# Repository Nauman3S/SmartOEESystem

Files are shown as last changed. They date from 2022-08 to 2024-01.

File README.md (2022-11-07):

<p align="center">
  <a href="" rel="noopener">
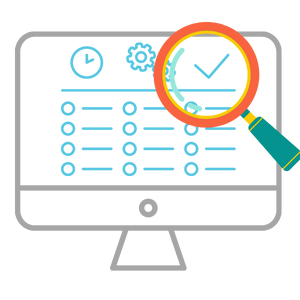
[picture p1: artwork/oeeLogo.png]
Project logo
 </a>
</p>

<h3 align="center">Smart OEE System</h3>

<div align="center">

[]()

</div>

---

<p align="center"> Smart OEE System
    <br> 
</p>

## 📝 Table of Contents

- [About](#about)
- [Getting Started](#getting_started)
- [RPiClient Installation](#Installation)
- [Circuit](#circuit)
- [Usage](#usage)
- [WebApp](#webapp)
- [Built Using](#built_using)
- [Authors](#authors)

## 🧐 About 

This repo contains

- Firmware
- Circuit Diagram
- Detailed instructions

for Smart OEE System.

## Getting Started 

These instructions will get you a copy of the project up and running on your system.

### Prerequisites

Things you need to install the FW.

```
- Arduino IDE
```

### Installing 

A step by step series that tell you how to get the Firmware and Backend running

#### ESP32 Configuration

You should have Arduino IDE Installed

  1.  Add ESP32 Board to your Arduino IDE
    1. In your Arduino IDE, go to File> Preferences
        Installing ESP32 Add-on in Arduino IDE Windows, Mac OS X, Linux open preferences
    2. Enter ```https://dl.espressif.com/dl/package_esp32_index.json``` 
        into the “Additional Board Manager URLs” field then, click the “OK” button:
        Note: if you already have the ESP32 boards URL, you can separate the URLs with a comma(each board will go to neaw line) as follows:
        ```https://dl.espressif.com/dl/package_esp32_index.json,\n http://arduino.esp8266.com/stable/package_esp8266com_index.json```

  2. Open the Boards Manager. Go to Tools > Board > Boards Manager…
  3. Search for ESP32 and press install button for the ESP32 by Espressif Systems“:
  4. That’s it. It should be installed after a few seconds.
  5.   In your Arduino sketchbook directory, create tools directory if it doesn't exist yet.
  6.  Unpack the tool into tools directory(present in libs/ESP32FS-1.0.zip) (the path will look like <home_dir>/Arduino/tools/ESP32FS/tool/esp32fs.jar).
  7.  Close and re-open the Arduino IDE.

  8.  Now copy the contents of the libs folder to the libraries directory of your Arduino
      1. If you are using windows, the libraries directory will be Documents/Arduino/libraries

##### ESP32 Node FW Uploading
  1.  Select ESP32 Dev Module from Tools->Board->ESP32
  2.  Select the correct port from Tools->Port
  3.  Then open Firmware.ino file,
  4.  Select Tools > ESP32 Sketch Data Upload menu item. This should start uploading the files into ESP32 flash file system.
  5.  Now Upload the Code to your ESP32 Dev Module.
  6.  Your ESP32 is now ready to be used.

## Circuit 

### ESP32 Dev Module Pinout

Follow the pinout diagram given below to connect different components to your TTGO LORA32 board.

![LoraPinout](Circuit/ESP32-Pinout.jpg)

### Other Components

```http
Other components pin connection details
```

#### Temperature Sensor DHT22

```DHT22 Connections```

| DHT22 Pins | ESP32 Dev Module Pins| 
| :--- | :--- | 
| `DATA OUT` | `23` |
| `VCC` | `5V` |
| `GND` | `GND` | 

#### Photoelectric Sensor

```Photoelectric Sensor Connections```

`From 2x 10K Resistors' center to Pin 18 of ESP32`

#### Status LED

```LED Connections```

| LED Pins | ESP32 Dev Module | 
| :--- | :--- | 
| `Anode` | `D2 via 220Ω resistor` |
| `Cathode` | `GND` |
*D2 is also connected to the internal LED of ESP32 Dev Module*

#### SCT-013 

```SCT-013 Connections```

-   Voltage Divider with 2x 100KΩ resistors.
-   10uF capacitor connected between Voltage Divider Circuit Output and GND
-   3.5mm Audio Jack connected between Voltage Divider Circuit Output and ESP32 Pin 34.

The overall SCT-013 connection assembly will look something like shown in the diagram below.

![SCTConnection](Circuit/sctWiring.jpg)

The photoelectric sensor has three wires as shown below

![PESConnection](Circuit/pesSch.jpg)

### Complete Circuit Diagram

Here's the complete circuit diagram of the system.

![CircuitDiagram](Circuit/Circuit_bb.png)

## Usage 

1.  Power on your ESP32, it will present you with an AP named ```OEE``` (while ```OEE``` can be changed in the portal)
2.  Default captive portal password `12345678AP` which can be changed in captive portal.
3.  Connect to the ESP32 access point and open the web-browser and navigate to the link ```http://esp32.local/_ac```. This link will work on most of the operating systems but if your operating system is not allowing to open it, you may want to check the captive portal IP Address from the serial monitor and can use that IP address inplace of the above mentioned URL.
4.  The default access IP Address is ```http://192.168.4.1/_ac```
5.  You will be presented with a main dashboard as shown below(based on your device)
   ![SCR1](artwork/scr1.png)

5.  Once connected to a WiFi network, you can again access the captive portal using same URL or the IP Address from the Serial monitor.
6.  The data is published to the MQTT Topic ```OEE/{hostname}``` while the hostname is the one which you can define in Settings page of the captive portal.

### Changing Timezone

1.  Open Settings tab
2.  Enter timezone string from https://en.wikipedia.org/wiki/List_of_tz_database_time_zones 'TZ database name' column.
3.  Click Save&Start

### API Endpoints and HTML URLS
```API Endpoints```

| Endpoint | Description | 
| :--- | :--- | 
| `/api-now` | `API: live sensor readings in JSON format` |
| `/api` | `API: historical sensors data in JSON format` |
| `/LiveSensors` | `HTML PAGE: Live Sensor Data` |
| `/data` | `HTML PAGE: Historical Sensor Data` | 
| `/mqtt_settings` | `HTML PAGE: Settings. Default username: AP Name, Default Password: admin` | 
| `/_ac` | `HTML PAGE: Main Captive portal page` | 
| `/` | `HTML PAGE: Historical Sensor Data` | 

1.  **Connect to WiFi** tab allows searching of nearby WiFi APs and adding them to the ESP32.
   ![SCR3](artwork/scr3.png)
7.  **Saved WiFi Networks** tab allows connecting to the saved access points.
   ![SCR4](artwork/scr4.png)
8.  **Reset...** tab allows reseting of the device to factory settings.
    ![SCR5](artwork/scr5.png)
9.  **Settings** tab contains settings related to MQTT and sensors.
    ![SCR6](artwork/scr6.png)
10. **api-now** tab gives the live-sensor data in JSON format.
    ![SCR7](artwork/scr7.png)
11. **api** tab gives the historical sensor data acquired after every 5 mintues.
    ![SCR9](artwork/scr9.png)
13. **LiveSensors** tab shows live values of the sensors.
    ![SCR8](artwork/scr8.png)
12. **HOME** tab shows historical sensor data in a HTML table form acquired after every 5 minutes.
    ![SCR10](artwork/scr10.png)

## Web App 

[Dashboard Link: https://smartoeesystem.production.rehanshakir.com/](https://smartoeesystem.production.rehanshakir.com/)

You can access the webapp with following test acccount credentials

**Test Client**

*   Email Address: `howto0158@gmail.com`
*   Password: `1234`

**Admin**

*   Email Address: `admin@smartoee.com`
*   Password: `12345678`

### Dashboard Screenshots

 ![SCR11](artwork/db1.png) - Sign-in
 ![SCR12](artwork/db2.png) - Sign-up

 **Admin Dashboard**

 ![SCR13](artwork/db3.png) - Main Dashboard
 ![SCR14](artwork/db4.png) - Devices/Sensors Page
 ![SCR15](artwork/db5.png) - Adding a new Device/Sensor
 ![SCR16](artwork/db6.png) - Devices Management Page
 ![SCR17](artwork/db7.png) - User Profile

 **Client Dashboard**
 ![SCR18](artwork/cdb1.png) - Main Client Dashboard
 ![SCR19](artwork/cbd2.png) - Updating energy cost
 ![SCR20](artwork/cdb3.png) - Devices Management
 ![SCR21](artwork/cdb4.png) - Adding a new device
 ![SCR22](artwork/cdb5.png) - User Profile

### MQTT Details

From Device the data should be published to the topic `smartoee/data/#` in the format below:
* Replace `#` with the device MAC Address.

```json
{
  "macAddress": "FE064CSF",
  "oee":"20",
  "temperature":"30",
  "humidity":"45",
  "watts":"19"
}
```

Any change detected in the values will generate an alarm(as set in the dashboard) and will publish the value on the topic `{MAC Address}/smartoee` of the device.

## List of Components 

Following components are used to make this project

1.  [ESP32 Dev Kit Module](https://www.amazon.com/HiLetgo-ESP-WROOM-32-Development-Microcontroller-Integrated/dp/B0718T232Z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)

2.  [Current Sensor (SCT-013)](https://www.amazon.com/dp/B083S6YG36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)

or

2.  [Current Sensor 200A](https://www.amazon.com/Current-Sensor-Transformer-Energy-Meter/dp/B0B91R55TS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)

3.  [DHT22 Temperature and Humidity Sensor](https://www.amazon.com/Gowoops-Temperature-Humidity-Measurement-Raspberry/dp/B073F472JL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)

4.  [Vibration Sensor (IMU) (MPU6050)](https://www.amazon.com/HiLetgo-MPU-6050-Accelerometer-Gyroscope-Converter/dp/B00LP25V1A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)

5. [Photoelectric Sensor](https://www.amazon.com/IKSACE-Photoelectric-Switchable-Retroreflective-photoelectric/dp/B08KRQ7M1P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)

6.  [Generic 3.5mm Green/Red/Blue LEDs](https://www.amazon.com/MCIGICM-Circuit-Assorted-Science-Experiment/dp/B07PG84V17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)

7.  [Generic 3.5mm Audio Jack with Screw Terminals](https://www.amazon.com/Cerrxian-Terminal-Headphone-Converter-Adapter/dp/B06WRRGYMM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)

8.  [Generic 10uF 25v Capacitor](https://www.amazon.com/Tnisesm-Electrolytic-Capacitor-Aluminum-10UF-25V-4X7/dp/B089YCK59V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)

9.  [Generic 220Ω Resistors](https://www.amazon.com/BOJACK-Single-Resistor-Resistors-200pcs/dp/B07PFFF1VK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)

10. [Generic 10KΩ Resistors](https://www.amazon.com/EDGELEC-Resistor-Tolerance-Multiple-Resistance/dp/B07QJB31M7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)

11. [Generic 100KΩ Resistors](https://www.amazon.com/Resistor-Tolerance-Resistors-Limiting-Certificated/dp/B08QRSQB18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)

12.  [Generic 5V USB Micro B cable and adapter](https://www.amazon.com/Travel-Charger-Adapter-Samsung-Galaxy/dp/B0117O020U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)

13. [Micro USB Cable](https://www.amazon.com/Android-Charger-sweguard-Charging-Phone-Grey/dp/B09MT18H3J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)

14. [Breadboard, Jumper Wires and Power Supply Module](https://www.amazon.com/HUAREW-Breadboard-Wires%EF%BC%8CBattery-Clip%EF%BC%8C830-tie-Points/dp/B09TX9CMG1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)

15. [Jumper Wires](https://www.amazon.com/EDGELEC-Breadboard-Optional-Assorted-Multicolored/dp/B07GD2BWPY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)

16. [12V 3A Adapter](https://www.amazon.com/GOOKYO-Charger-Switching-Replacement-Adapter/dp/B095S61GFH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)

## ⛏️ Built Using 

- [Python](https://www.python.org/) - For Cloud Gateway Pogramming
- [Arduino](https://www.arduino.cc/) - Embedded Framework and IDE - For Sensor Node Design

## 📹 Demo Videos 

-   [Device Demo Video](https://youtu.be/jB85V6VlB9w) - OEE Device Demo Video

## ✍️ Authors 

- [@Nauman3S](https://github.com/Nauman3S) - Development and Deployment

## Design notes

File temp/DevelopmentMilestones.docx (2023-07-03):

Below, provided is the rough time estimates for simple implementation of each feature, assuming that the current backend infrastructure (NodeJS), frontend (ReactJS), and database (MongoDB) are all in good shape and dockerized using CapRover. Please note that these estimates are tentative and subject to change based on potential unforeseen complexities or challenges:

1. Display production line name: 2 days. This requires creating an input field, updating the database schema, and allowing for real-time updates.
2. Product Name: 2 days. Similar to feature 1, this also requires real-time updates.
3. Display running (green) Line Stopped (red): 3-4 days. This involves reading sensor data in real-time and updating the display based on predefined conditions.
4. Shift Start Time: 2 days. The system needs to recognize when a shift starts, based on sensor data or user input.
5. Shift Duration timer: 2-3 days. This involves real-time tracking of shift duration.
6. Shift Downtime: 3-4 days. Implementing this feature involves keeping track of sensor inactivity and calculating downtime as a percentage of total shift time.
7. Units Per Minute: 3-4 days. The system must track production units in real-time and calculate a rate per minute.
8. Target Today: 2 days. This feature requires an input field for target setting and updating the database schema.
9. Progress Chart: 4-5 days. This feature requires generating and updating a real-time progress chart based on current progress against target.
10. OEE Chart: 4-5 days. The system must calculate OEE (Overall Equipment Efficiency) parameters and display them in a dynamic chart.
11. Line Performance Each Day: 4-5 days. This feature involves storing daily data and generating bar charts.
12. Client can print report/PDF: 4-5 days. The system must compile data into a report and generate a PDF that the user can print.

Total Development Time Required: 36 - 43 days

These timeframes are rough estimates and assume an uninterrupted workflow. Testing, bug fixing, and additional adjustments could potentially extend these estimates further. Each feature will require careful design, implementation, and testing to ensure its seamless integration with the existing system. If the list of requirements increases or the specifics of these features become more complex, the timeline would also need to be adjusted accordingly.

Please keep in mind that any significant alterations to the backend might require additional time, especially if they impact the underlying database schema or the data handling processes.

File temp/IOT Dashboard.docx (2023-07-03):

IOT Dashboard

Dashboard will have cpanel login specific to each client. Each client will have multiple production lines displayed on the home screen. As per chat, the admin can add sensors, data etc. It shows real time & date.

The formula’s and displays required:

1. Display production line name: Eg: Line 1 (edited by user)
2. Product Name: (edited by user)
3. Display running (green) Line Stopped (red)
4. Shift Start Time:
5. Shift Duration: timer
6. Shift Downtime: (minutes) also display as % of total shift duration
7. Units Per Minute (calculated per minute)
8. Target Today: (edited by user)
9. Progress Chart: Showing on target, not on target, progress bar. Showing total units produced currently.
10. OEE chart (traffic light %)
11. Line Performance Each Day: Showing bar chart for each day Monday – Sunday of the past week.
1. Box to display name of line: eg: Pouch Line / Line 1 (edited by user)
2. Box to display name of product: eg: Chocolate Biscuit (edited by user)
3. Running in green or Line Stopped in red. (Green if photo electric sensor at beginning of line is activated consistently for 15 seconds. Red if photo electric sensor is not activated during 60 second period.
4. As soon as sensor is activated at beginning of day.
5. Timer set once shift starts
6. Number of minutes there is downtime / no activation of photo sensors beginning & end of line. (% downtime formula is number of minutes / total shift time)
7. Units per minute calculation box (calculated each minute) shows graph of units per minute per minute / per hour
8. Target Today (Set / edited by user)
9. Progress Chart (ON TARGET / NOT ON TARGET) Progress Bar showing 0 – 100% (based on user setting target). Showing total units produced currently.
10. OEE Chart (circle – performance, availability, quality)
11. Displays total values of each line each day by total units.
12. Client can print report / PDF for each line or total lines for each day.

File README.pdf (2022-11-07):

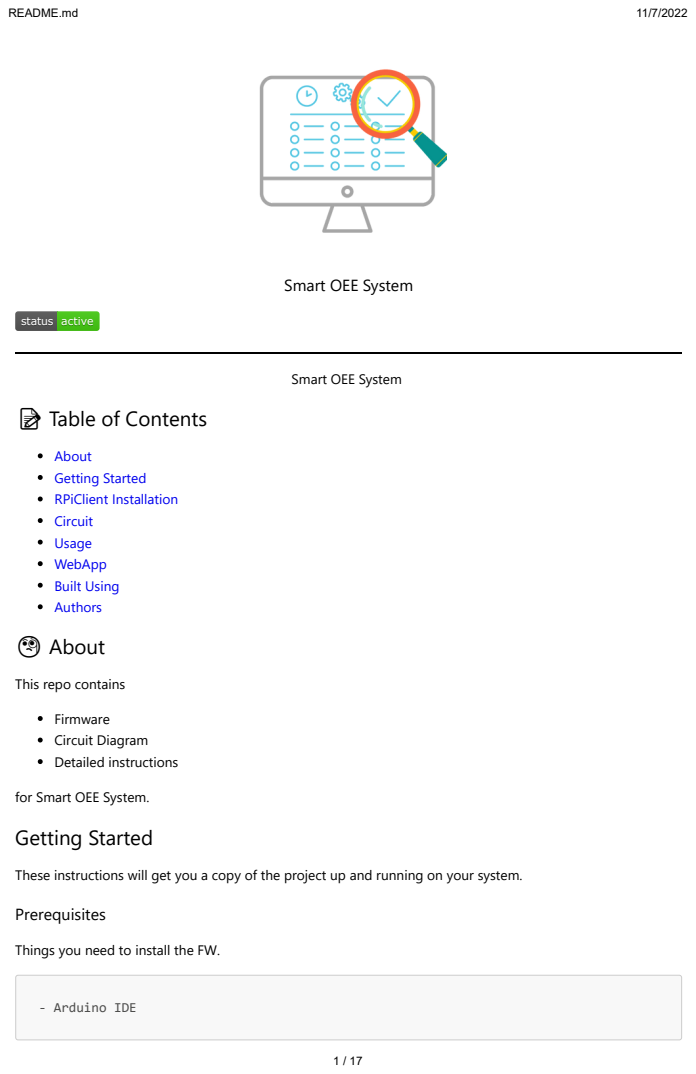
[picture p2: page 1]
README.md; ssttaattuuss; aaccttiivvee; About Getting Started RPiClient Installation Circuit Usage WebApp Built Using Authors 🧐 About; Firmware Circuit Diagram Detailed instructions; - Arduino IDE

Smart OEE System

📝 Table of Contents

This repo contains

for Smart OEE System.
Getting Started

These instructions will get you a copy of the project up and running on your system.
Prerequisites

Things you need to install the FW.

Installing

A step by step series that tell you how to get the Firmware and Backend running

ESP32 Configuration

You should have Arduino IDE Installed

1. Add ESP32 Board to your Arduino IDE 1. In your Arduino IDE, go to File> Preferences Installing ESP32 Add-on in Arduino IDE Windows, Mac OS X, Linux open preferences 2. Enter https://dl.espressif.com/dl/package_esp32_index.json into the “Additional Board Manager URLs” field then, click the “OK” button: Note: if you already have the ESP32 boards URL, you can separate the URLs with a comma(each board will go to neaw line) as follows: https://dl.espressif.com/dl/package_esp32_index.json,\nhttp://arduino.esp8266.com/stable/package_esp8266com_index.json
2. Open the Boards Manager. Go to Tools > Board > Boards Manager…
3. Search for ESP32 and press install button for the ESP32 by Espressif Systems“:
4. That’s it. It should be installed after a few seconds.
5. In your Arduino sketchbook directory, create tools directory if it doesn't exist yet.
6. Unpack the tool into tools directory(present in libs/ESP32FS-1.0.zip) (the path will look like <home_dir>/Arduino/tools/ESP32FS/tool/esp32fs.jar).
7. Close and re-open the Arduino IDE.
8. Now copy the contents of the libs folder to the libraries directory of your Arduino
1. If you are using windows, the libraries directory will be Documents/Arduino/libraries

ESP32 Node FW Uploading

1. Select ESP32 Dev Module from Tools->Board->ESP32
2. Select the correct port from Tools->Port
3. Then open Firmware.ino file,
4. Select Tools > ESP32 Sketch Data Upload menu item. This should start uploading the files into ESP32 flash file system.
5. Now Upload the Code to your ESP32 Dev Module.
6. Your ESP32 is now ready to be used.

## Circuit

ESP32 Dev Module Pinout

Follow the pinout diagram given below to connect different components to your TTGO LORA32 board.

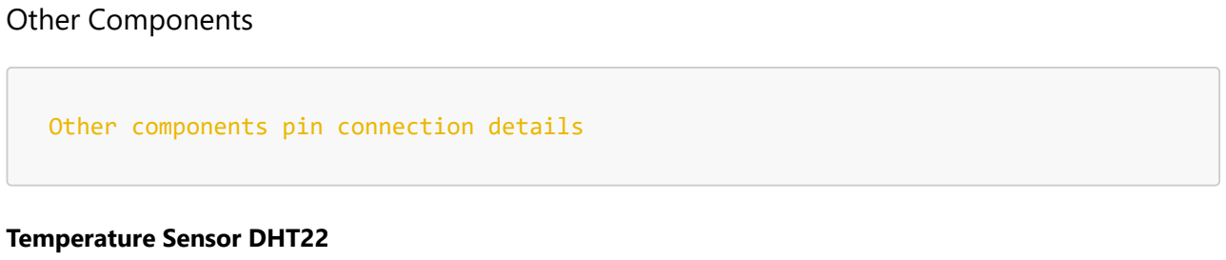
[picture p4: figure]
Other Components; Other components pin connection details; Temperature Sensor DHT22

DHT22 Connections

DHT22 Pins ESP32 Dev Module Pins

DATA OUT | 23
VCC | 5V
GND | GND

Photoelectric Sensor

Photoelectric Sensor Connections

From 2x 10K Resistors' center to Pin 18 of ESP32

Status LED

LED Connections

LED Pins ESP32 Dev Module

LED Pins ESP32 Dev Module

Anode | D2 via 220Ω resistor
Cathode | GND

D2 is also connected to the internal LED of ESP32 Dev Module

SCT-013

SCT-013 Connections

Voltage Divider with 2x 100KΩ resistors.
10uF capacitor connected between Voltage Divider Circuit Output and GND
3.5mm Audio Jack connected between Voltage Divider Circuit Output and ESP32 Pin 34.

The overall SCT-013 connection assembly will look something like shown in the diagram below.

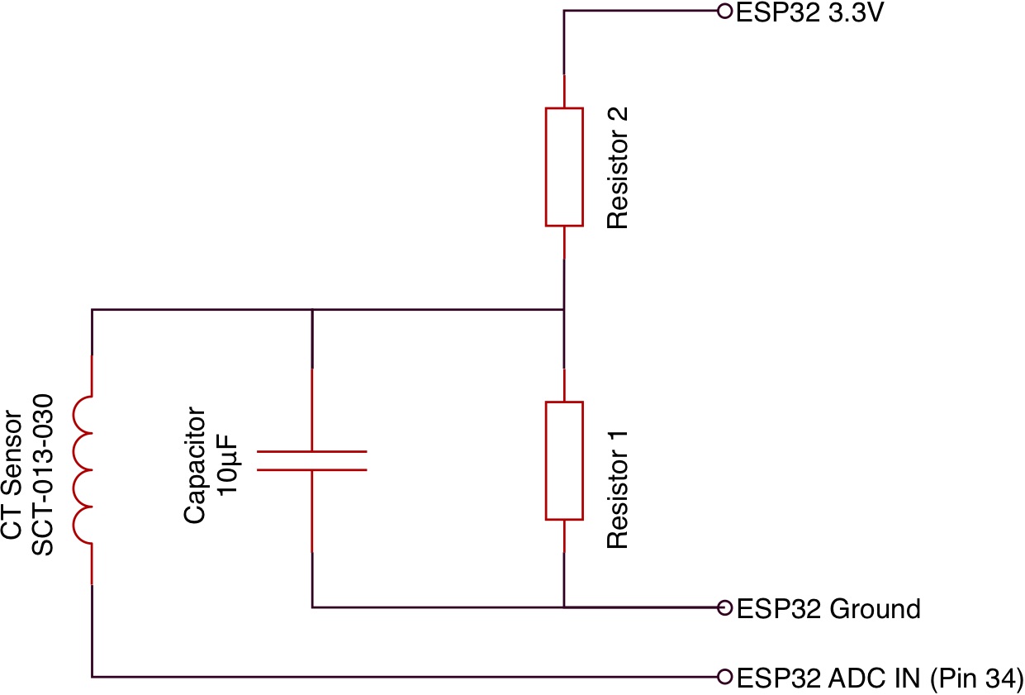
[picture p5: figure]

The photoelectric sensor has three wires as shown below

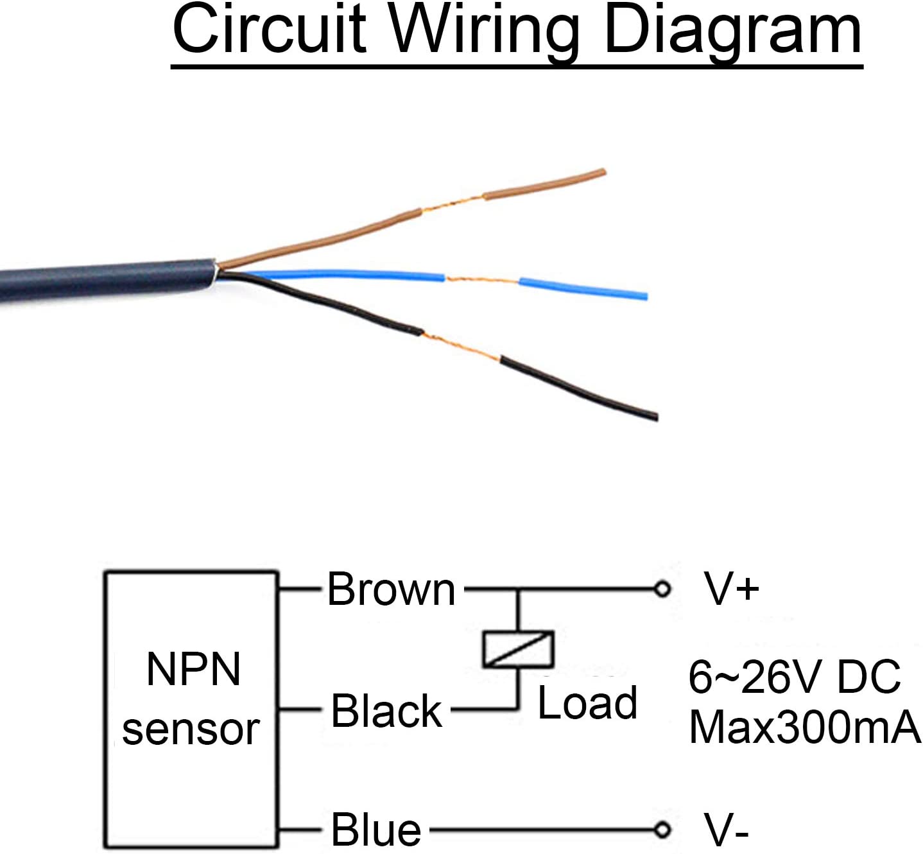
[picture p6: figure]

Complete Circuit Diagram

Here's the complete circuit diagram of the system.

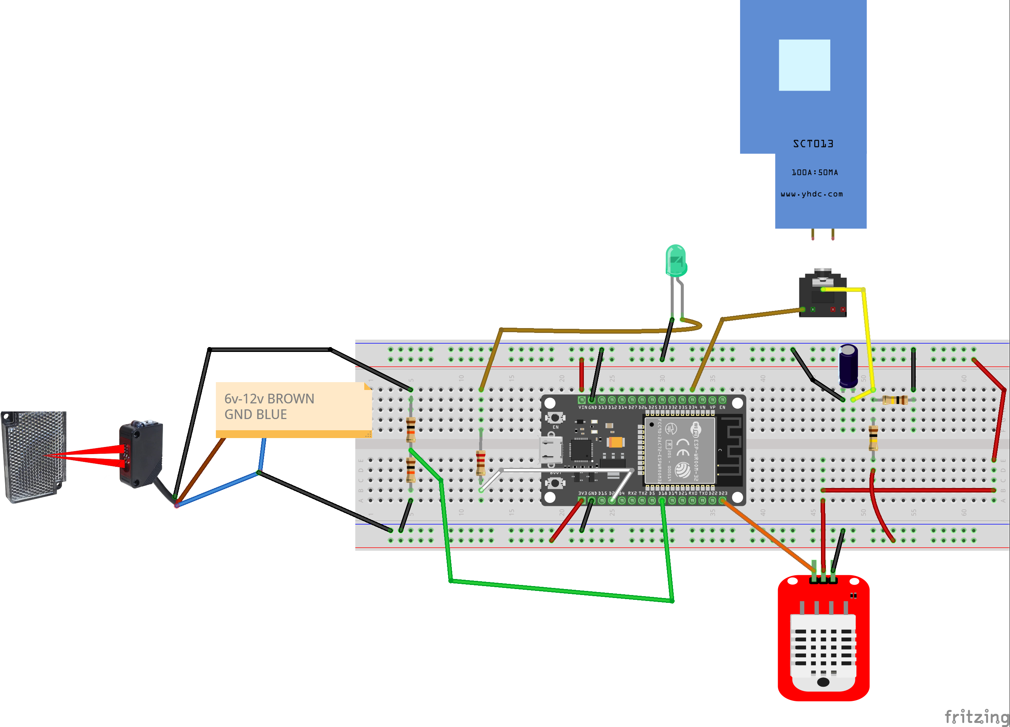
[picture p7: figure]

## Usage

1. Power on your ESP32, it will present you with an AP named OEE (while OEE can be changed in the portal)
2. Default captive portal password 12345678AP which can be changed in captive portal.
3. Connect to the ESP32 access point and open the web-browser and navigate to the link http://esp32.local/_ac. This link will work on most of the operating systems but if your operating system is not allowing to open it, you may want to check the captive portal IP Address from the serial monitor and can use that IP address inplace of the above mentioned URL.
4. The default access IP Address is http://192.168.4.1/_ac

5. You will be presented with a main dashboard as shown below(based on your device)

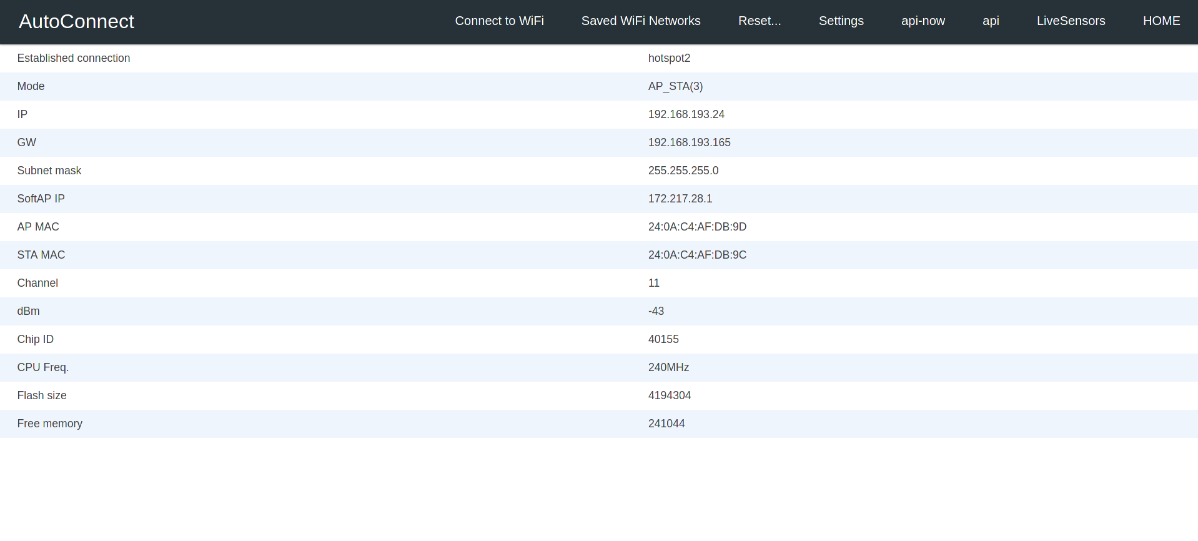
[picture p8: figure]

6. Once connected to a WiFi network, you can again access the captive portal using same URL or the IP Address from the Serial monitor.
7. The data is published to the MQTT Topic OEE/{hostname} while the hostname is the one which you can define in Settings page of the captive portal.
Changing Timezone
1. Open Settings tab
2. Enter timezone string from https://en.wikipedia.org/wiki/List_of_tz_database_time_zones 'TZ database name' column.
3. Click Save&Start
API Endpoints and HTML URLS

API Endpoints

Endpoint | Description
/api-now | API: live sensor readings in JSON format
/api | API: historical sensors data in JSON format
/LiveSensors | HTML PAGE: Live Sensor Data
/data | HTML PAGE: Historical Sensor Data
/mqtt_settings | HTML PAGE: Settings. Default username: AP Name, Default Password: admin
/_ac | HTML PAGE: Main Captive portal page
/ | HTML PAGE: Historical Sensor Data

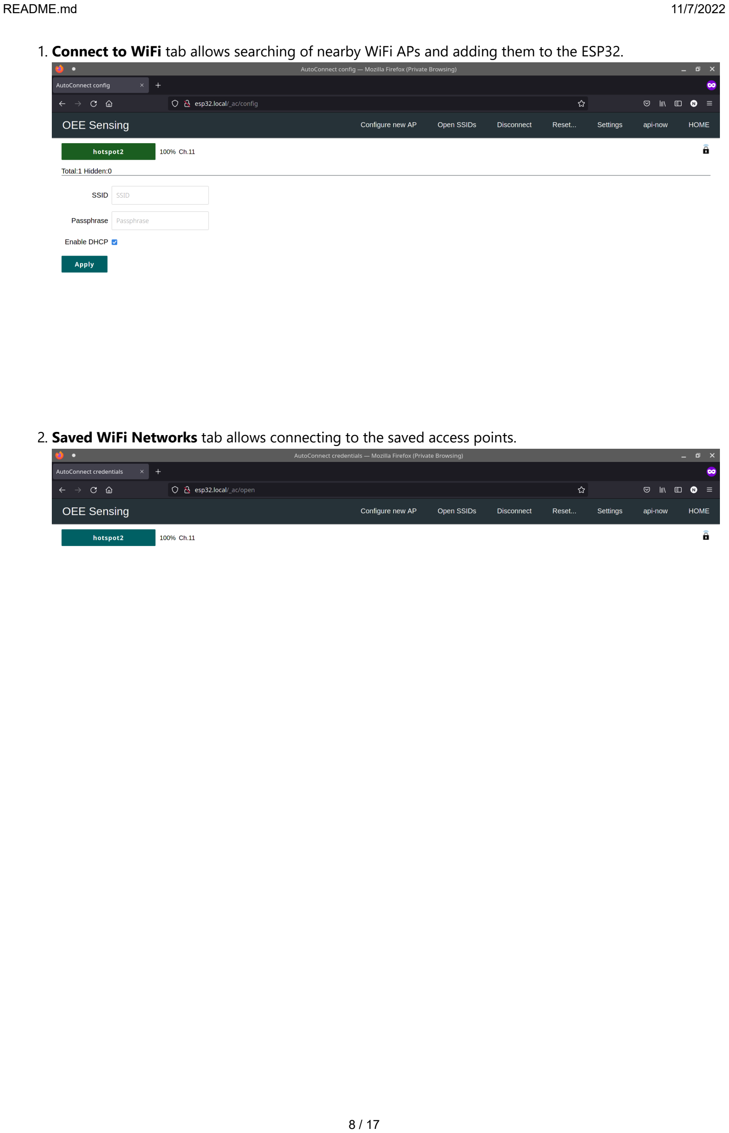
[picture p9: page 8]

1. Connect to WiFi tab allows searching of nearby WiFi APs and adding them to the ESP32.
2. Saved WiFi Networks tab allows connecting to the saved access points.

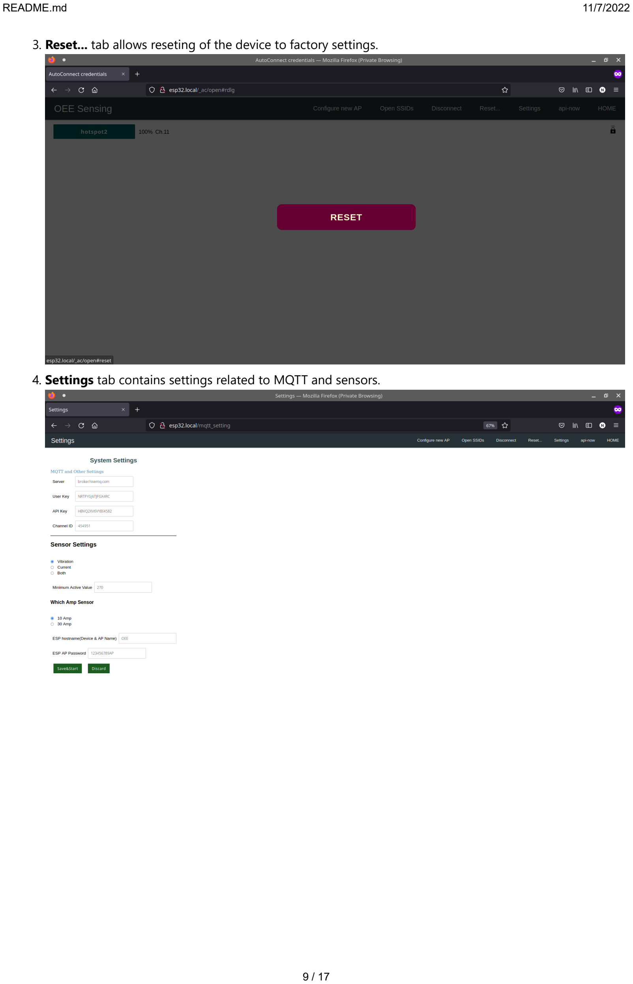
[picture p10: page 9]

3. Reset... tab allows reseting of the device to factory settings.
4. Settings tab contains settings related to MQTT and sensors.

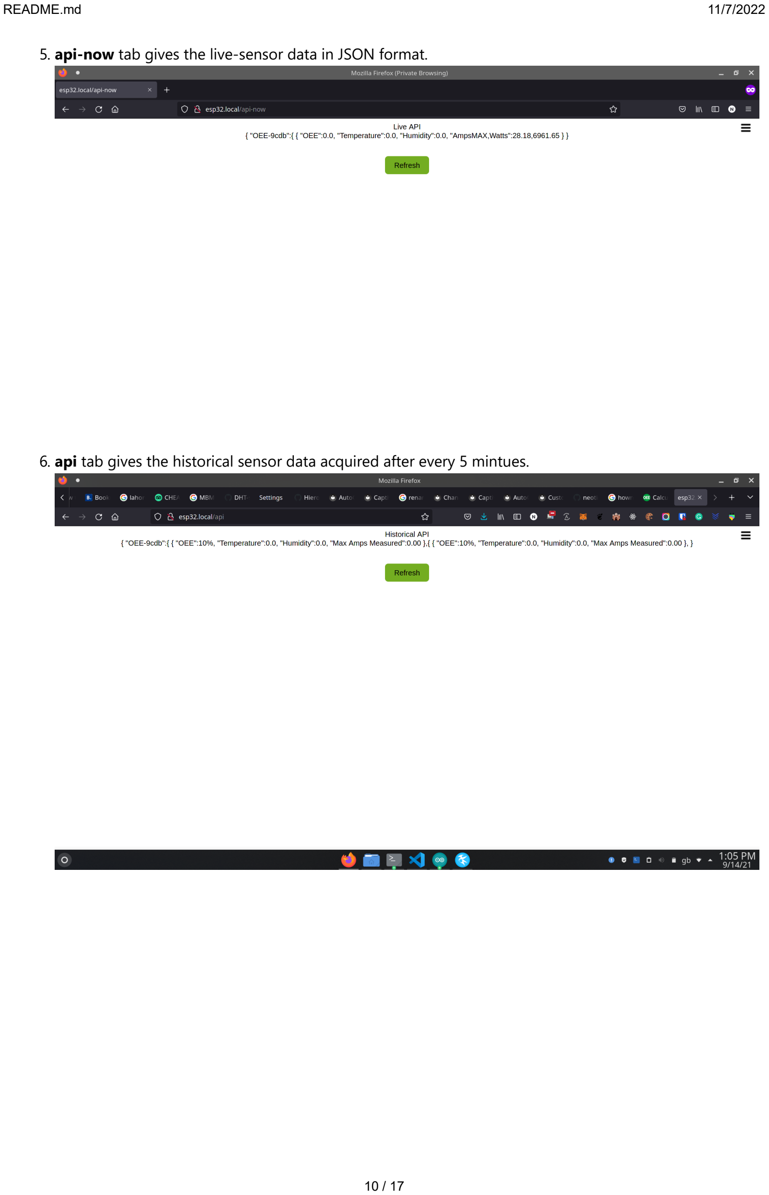
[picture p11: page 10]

5. api-now tab gives the live-sensor data in JSON format.
6. api tab gives the historical sensor data acquired after every 5 mintues.

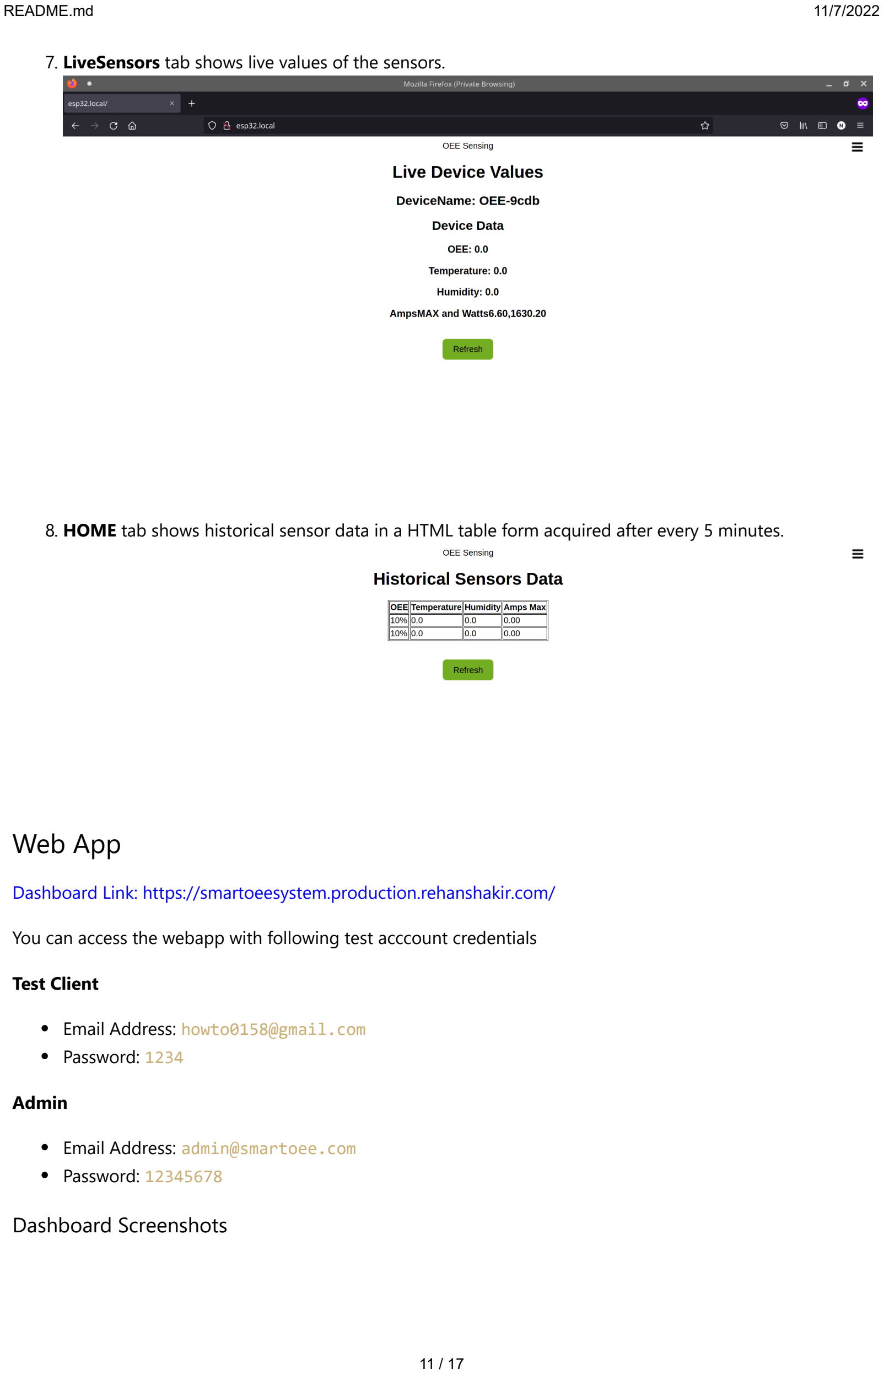
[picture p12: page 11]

7. LiveSensors tab shows live values of the sensors.
8. HOME tab shows historical sensor data in a HTML table form acquired after every 5 minutes.

## Web App

Dashboard Link: https://smartoeesystem.production.rehanshakir.com/

You can access the webapp with following test acccount credentials

Test Client

Email Address: howto0158@gmail.com
Password: 1234

Admin

Email Address: admin@smartoee.com Password: 12345678
Dashboard Screenshots

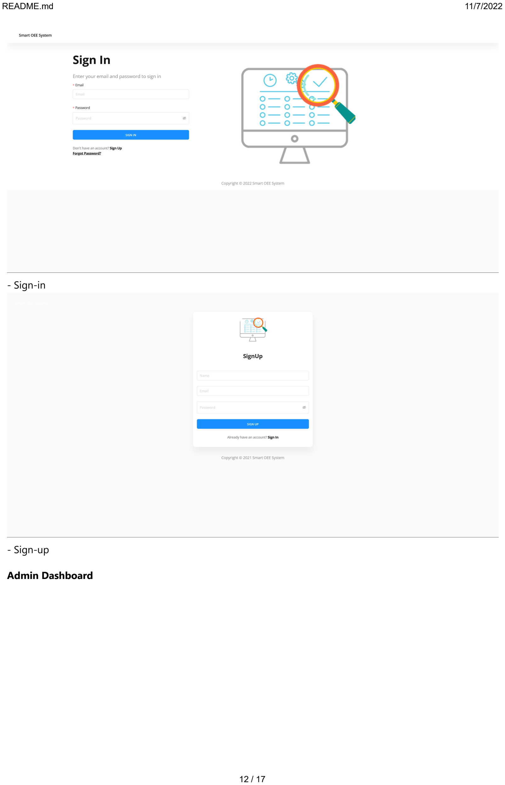
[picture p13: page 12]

- Sign-in
- Sign-up

Admin Dashboard

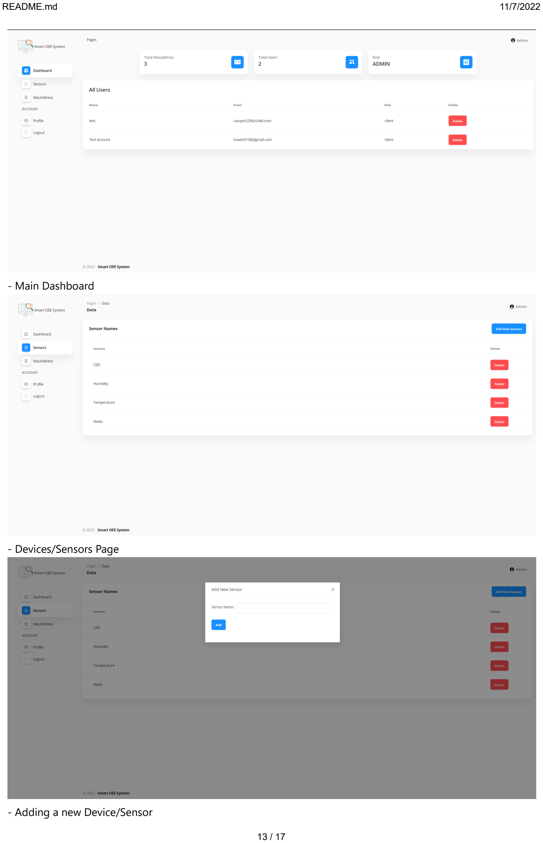
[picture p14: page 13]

- Main Dashboard
- Devices/Sensors Page
- Adding a new Device/Sensor

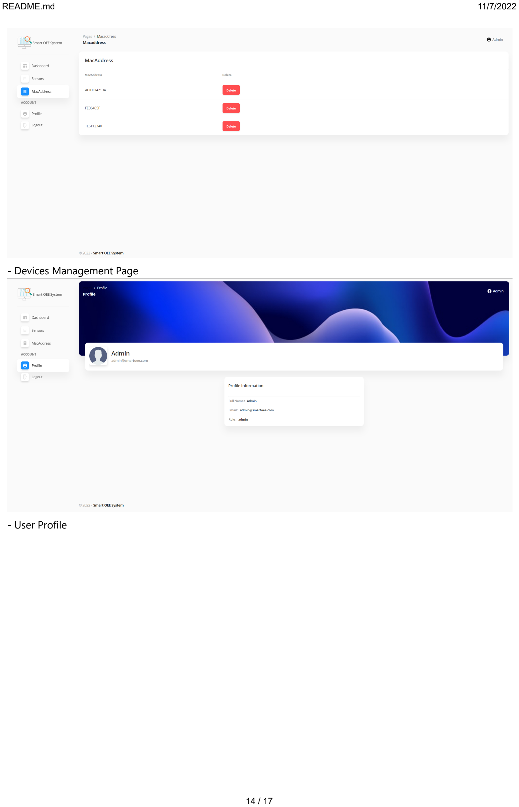
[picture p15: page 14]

- Devices Management Page
- User Profile

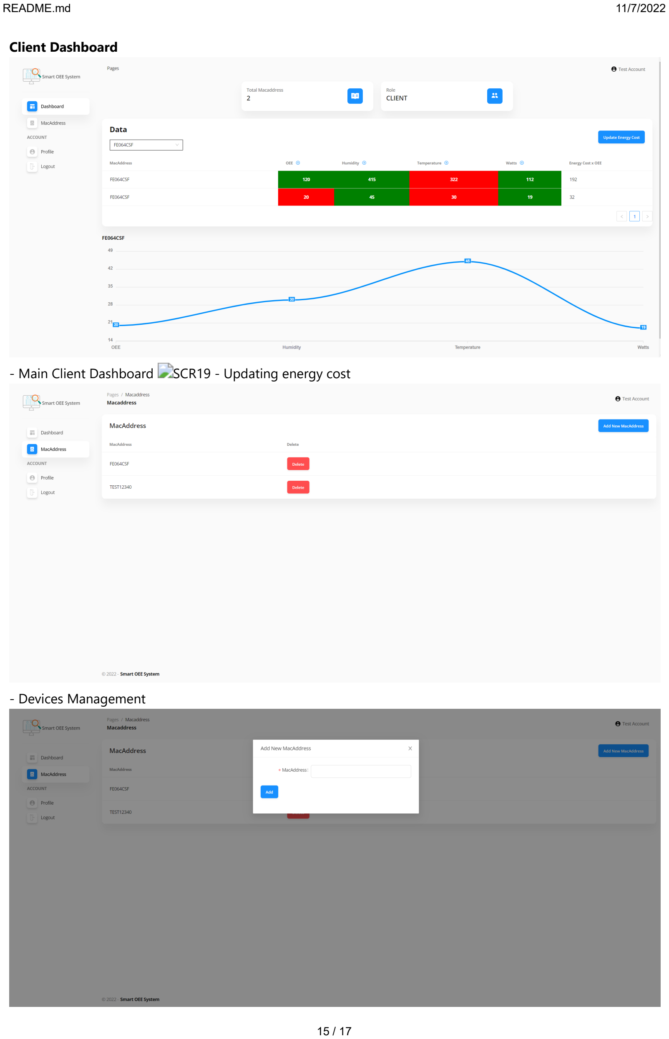
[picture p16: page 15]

Client Dashboard

- Main Client Dashboard SCR19 - Updating energy cost
- Devices Management

- Adding a new device

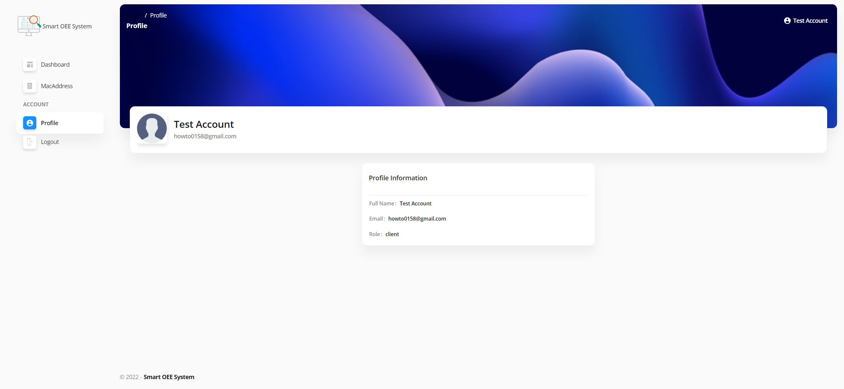
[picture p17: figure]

- User Profile
MQTT Details

From Device the data should be published to the topic smartoee/data/# in the format below

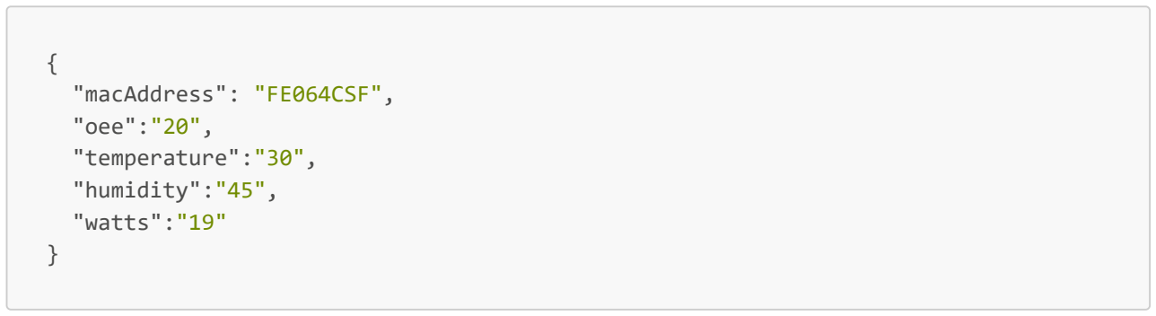
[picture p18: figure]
"macAddress": "FE064CSF", "oee":"20", "temperature":"30", "humidity":"45", "watts":"19"

Any change detected in the values will generate an alarm(as set in the dashboard) and will publish the value on the topic {MAC Address}/smartoee of the device.

## List of Components

Following components are used to make this project

1. ESP32 Dev Kit Module (https://www.amazon.com/HiLetgo-ESP-WROOM-32-Development-Microcontroller-Integrated/dp/B0718T232Z)
2. Current Sensor (SCT-013) (https://www.amazon.com/dp/B083S6YG36)

or

2. Current Sensor 200A (https://www.amazon.com/Current-Sensor-Transformer-Energy-Meter/dp/B0B91R55TS)
3. DHT22 Temperature and Humidity Sensor (https://www.amazon.com/Gowoops-Temperature-Humidity-Measurement-Raspberry/dp/B073F472JL)
4. Vibration Sensor (IMU) (MPU6050) (https://www.amazon.com/HiLetgo-MPU-6050-Accelerometer-Gyroscope-Converter/dp/B00LP25V1A)
5. Photoelectric Sensor (https://www.amazon.com/IKSACE-Photoelectric-Switchable-Retroreflective-photoelectric/dp/B08KRQ7M1P)

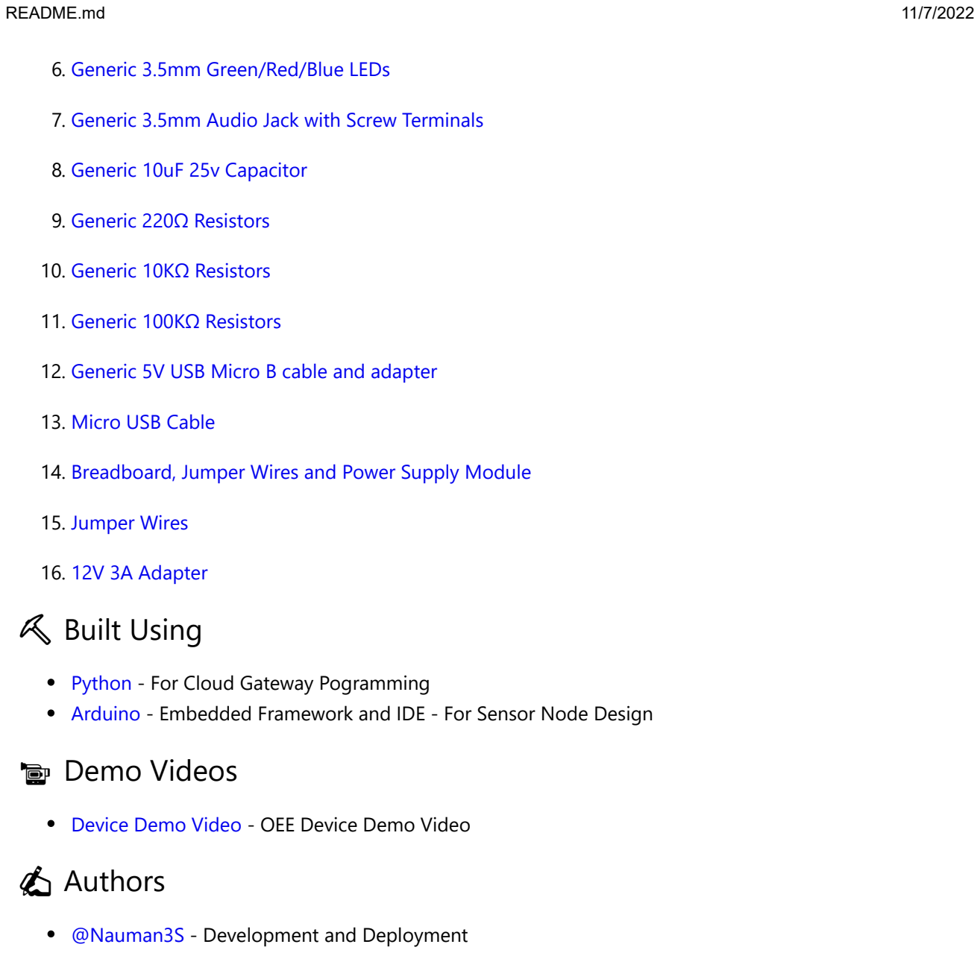
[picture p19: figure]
6. Generic 3.5mm Green/Red/Blue LEDs; 8. Generic 10uF 25v Capacitor; 9. Generic 220Ω Resistors; 10. Generic 10KΩ Resistors; 11. Generic 100KΩ Resistors; 13. Micro USB Cable; 15. Jumper Wires; 16. 12V 3A Adapter ⛏ Built Using; Python - For Cloud Gateway Pogramming; 📹 Demo Videos; ✍ Authors; @Nauman3S - Development and Deployment

7. Generic 3.5mm Audio Jack with Screw Terminals (https://www.amazon.com/Cerrxian-Terminal-Headphone-Converter-Adapter/dp/B06WRRGYMM)
12. Generic 5V USB Micro B cable and adapter (https://www.amazon.com/Travel-Charger-Adapter-Samsung-Galaxy/dp/B0117O020U)
14. Breadboard, Jumper Wires and Power Supply Module (https://www.amazon.com/HUAREW-Breadboard-Wires%EF%BC%8CBattery-Clip%EF%BC%8C830-tie-Points/dp/B09TX9CMG1)

Arduino (https://www.arduino.cc/) - Embedded Framework and IDE - For Sensor Node Design

Device Demo Video (https://youtu.be/jB85V6VlB9w) - OEE Device Demo Video

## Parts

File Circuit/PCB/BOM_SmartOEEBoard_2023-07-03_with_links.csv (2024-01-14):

ID | Name | Designator | Footprint | Quantity | Manufacturer Part | Manufacturer | Supplier | Supplier Part | Price | Resistance (Ohms) | link
1 | 10uF | C1,C4,C10 | C0603 | 3 | 0603X106K100CT | Walsin(华新科) | LCSC | C2840513 | 0.011 |  | https://www.lcsc.com/product-detail/Multilayer-Ceramic-Capacitors-MLCC-SMD-SMT_Walsin-Tech-Corp-0603X106K100CT_C2840513.html
2 | 10uF | C2,C6,C8 | C0603 | 3 | C0603X5R106M160NT | SANYEAR(叁叶源) | LCSC | C466781 | 0.027 |  | https://www.lcsc.com/product-detail/Multilayer-Ceramic-Capacitors-MLCC-SMD-SMT_SANYEAR-C0603X5R106M160NT_C466781.html
3 | 1uF | C3,C5,C7 | C0603 | 3 | CC0603KRX7R6BB105 | YAGEO(国巨) | LCSC | C113807 | 0.008 |  | https://www.lcsc.com/product-detail/Multilayer-Ceramic-Capacitors-MLCC-SMD-SMT_YAGEO-CC0603KRX7R6BB105_C113807.html
4 | THT Pad | J1,J2,J3,J4,J5,J6,J7,J8,J9,J10,J11,J12,J14,J15,J16,J19,J20,J21,J22,J32,J34,J35,J36,J37,J38 | THT PAD | 25
5 | LTL-4221N | LED2 | LED-TH_BD3.0-P2.54-RD-RED | 1 | LTL-4221N | LITEON(光宝) | LCSC | C125081 | 0.046 |  | https://www.lcsc.com/product-detail/Light-Emitting-Diodes-LED_Lite-On-LTL-4221N_C125081.html
6 | XL-304UBC | LED3 | LED-TH_BD3.8-P2.54-FD_BLUE | 1 | XL-304UBC | XINGLIGHT(成兴光) | LCSC | C2895465 | 0.024 |  | https://www.lcsc.com/product-detail/Light-Emitting-Diodes-LED_XINGLIGHT-XL-304UBC_C2895465.html
7 | WJ128V-5.0-2P | P1 | CONN-TH_2P-P5.00_WJ128V-5.0-2P | 1 | WJ128V-5.0-2P | KANGNEX(康奈克斯电气) | LCSC | C8269 | 0.114 |  | https://www.lcsc.com/product-detail/Screw-terminal_Ningbo-Kangnex-Elec-WJ128V-5-0-2P_C8269.html
8 | MMBT2222ALT1G | Q1,Q2 | SOT-23-3_L2.9-W1.3-P1.90-LS2.4-BR | 2 | MMBT2222ALT1G | onsemi(安森美) | LCSC | C82460 | 0.033 |  | https://www.lcsc.com/product-detail/Bipolar-Transistors-BJT_onsemi-MMBT2222ALT1G_C82460.html
9 | 4.7kΩ | R1,R2 | RES-TH_BD2.3-L6.5-P10.50-D0.5 | 2 | CF1/4W-4.7KΩ±5% T | CCO(千志电子) | LCSC | C120071 | 0.008 | 4.7K | https://www.lcsc.com/product-detail/Through-Hole-Resistors_CCO-Chian-Chia-Elec-CF1-4W-4-7K-5-T_C120071.html
10 | 10kΩ | R3,R5,R8,R9,R11,R14,R15,R17,R20,R21 | RES-TH_BD2.3-L6.5-P10.50-D0.5 | 10 | MF1/4W-10KΩ±1% T | CCO(千志电子) | LCSC | C119347 | 0.012 | 10K | https://www.lcsc.com/product-detail/Through-Hole-Resistors_CCO-Chian-Chia-Elec-MF1-4W-10K-1-T_C119347.html
11 | 20kΩ | R4,R6,R13,R16,R18,R19 | RES-TH_BD2.3-L6.5-P10.50-D0.5 | 6 | CF1/4W-20KΩ±5% T | CCO(千志电子) | LCSC | C120086 | 0.006 | 20K | https://www.lcsc.com/product-detail/Through-Hole-Resistors_CCO-Chian-Chia-Elec-CF1-4W-20K-5-T_C120086.html
12 | 330Ω | R7,R12 | RES-TH_BD2.2-L6.5-P10.50-D0.6 | 2 | MF1/4CCT52A3300F | KOA | LCSC | C315657 | 0.083 | 330 | https://www.lcsc.com/product-detail/Through-Hole-Resistors_KOA-Speer-Elec-MF1-4CCT52A3300F_C315657.html
13 | 1kΩ | R10 | RES-TH_BD2.3-L6.5-P10.50-D0.5 | 1 | CF1/4W-1KΩ±5% T | CCO(千志电子) | LCSC | C120055 | 0.006 | 1K | https://www.lcsc.com/product-detail/Through-Hole-Resistors_CCO-Chian-Chia-Elec-CF1-4W-1K-5-T_C120055.html
14 | VDR | R22 | RES-TH_L9.6-W5.6-P5.00-D0.7-S3.00 | 1 | VDR-07D241K | VDR(嵩隆) | LCSC | C283926 | 0.033 |  | https://www.lcsc.com/product-detail/Varistors_VDR-Varistor-VDR-07D241K_C283926.html
15 | AC relay | RL1,RL2,RL3,RL4 | FINDER RELAY 40.51 | 4 |  |  |  |  |  |  | https://www.findernet.com/en/worldwide/series/40-series-miniature-pcb-relays-8-10-12-16a/type/type-4051-pcb-plug-in-relay-12a/
16 | KMR231GLFS | SW1 | KEY-SMD_KMR2XXGXXX | 1 | KMR231GLFS | C&K | LCSC | C99271 | 0.368 |  | https://www.lcsc.com/product-detail/Tactile-Switches_C-K-KMR231GLFS_C99271.html
17 | SS-12F18-G040 | SW2 | SW-TH_G-SWITCH_SS-12F18-G040 | 1 | SS-12F18-G040 | G-Switch(品赞) | LCSC | C2848918 | 0.096 |  | https://www.lcsc.com/product-detail/Slide-Switches_G-Switch-SS-12F18-G040_C2848918.html
18 | ESP32-WROOM-32 | U1 | WIFIM-SMD_ESP32-WROOM-32-N4 | 1 | ESP32-WROOM-32-N4 | ESPRESSIF(乐鑫) | LCSC | C82899 | 3.207 |  | https://www.lcsc.com/product-detail/WiFi-Modules_Espressif-Systems-ESP32-WROOM-32-N4_C82899.html
19 | TPAP2112K-3.3TRG1 | U2,U3 | SOT-23-5_L2.9-W1.6-P0.95-LS2.8-BR | 2 | TPAP2112K-3.3TRG1 | TECH PUBLIC(台舟) | LCSC | C3021085 | 0.107 |  | https://www.lcsc.com/product-detail/Linear-Voltage-Regulators-LDO_TECH-PUBLIC-TPAP2112K-3-3TRG1_C3021085.html
20 | LED-TH | U4 | LED-TH_BD3.8-P2.28_GREEN | 1 | 绿发翠绿φ3直插长脚28mm | null | LCSC | C9900001201 |  |  | https://www.lcsc.com/product-detail/Light-Emitting-Diodes-span-style-background-color-ff0-LED-span_TONYU-DY-204SUGT-A3_C7470787.html
21 | CP2104-F03-GM | U5 | QFN-24_L4.0-W4.0-P0.50-BL-EP2.7 | 1 | CP2104-F03-GMR | SILICON LABS(芯科) | LCSC | C47742 | 1.906 |  | https://www.lcsc.com/product-detail/USB-ICs_SILICON-LABS-CP2104-F03-GMR_C47742.html
22 | 100kΩ | U6,U7,U15,U16 | RES-TH_BD2.5-L6.5-P10.50-D0.6 | 4 | RI40-1/4W-100KΩ±1%T | 华星机电 | LCSC | C714626 | 0.041 |  | https://www.lcsc.com/product-detail/Through-Hole-Resistors_Huaxing-Mechanical-Elec-RI40-1-4W-100K-1-T_C714626.html
23 | HLK-20M12 | U8 | PWRM-TH_HLK-20MXX | 1 | HLK-20M12 | HI-LINK(海凌科) | LCSC | C465408 | 2.892 |  | https://www.lcsc.com/product-detail/Power-Modules_HI-LINK-HLK-20M12_C465408.html
24 | HLK-5D1205 | U9 | PWRM-TH_HLK-5DXXXX | 1 | HLK-5D1205 | HI-LINK(海凌科) | LCSC | C474033 | 4.822 |  | https://www.lcsc.com/product-detail/Power-Modules_HI-LINK-HLK-5D1205_C474033.html
25 | KF127S-5.0-6P | U10,U11,U12,U13,U14 | CONN-TH_6P-P5.00_KEFA_KF127S-5.0-6P | 5 | KF127S-5.0-6P | KEFA(科发) | LCSC | C2974921 | 0.901 |  | https://www.lcsc.com/product-detail/Screw-terminal_Cixi-Kefa-Elec-KF127S-5-0-6P_C2974921.html
26 | JL128-50805G01 | U17 | CONN-TH_JL128-50005G01 | 1 | JL128-50805G01 | JILN(锦凌) | LCSC | C2961928 | 0.29 |  | https://www.lcsc.com/product-detail/Screw-terminal_JILN-JL128-50805G01_C2961928.html
27 | DHT22 | U18 | SENSOR-TH_HAIGU_DHT22 | 1 | DHT22 | HAIGU(广州海谷) | LCSC | C2880291 |  |  | https://www.lcsc.com/product-detail/Temperature-and-Humidity-Sensor_Aosong-Guangzhou-Elec-DHT11_C117051.html
28 | DB128L-5.0-8P-GN-S | U19 | CONN-TH_8P-P5.00_DB128L-5.0-8P-GN-S | 1 | DB128L-5.0-8P-GN-S | DIBO(地博电气) | LCSC | C430596 | 0.629 |  | https://www.lcsc.com/product-detail/Screw-terminal_DORABO-DB128L-5-0-8P-GN-S_C430596.html
29 | 1050171001 | USB1 | MICRO-USB-SMD_1050171001 | 1 | 1050171001 | MOLEX | LCSC | C505111 | 0.531 |  | https://www.lcsc.com/product-detail/USB-Connectors_MOLEX-1050171001_C505111.html

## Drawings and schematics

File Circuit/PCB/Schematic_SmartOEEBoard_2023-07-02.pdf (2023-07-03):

A | A

1

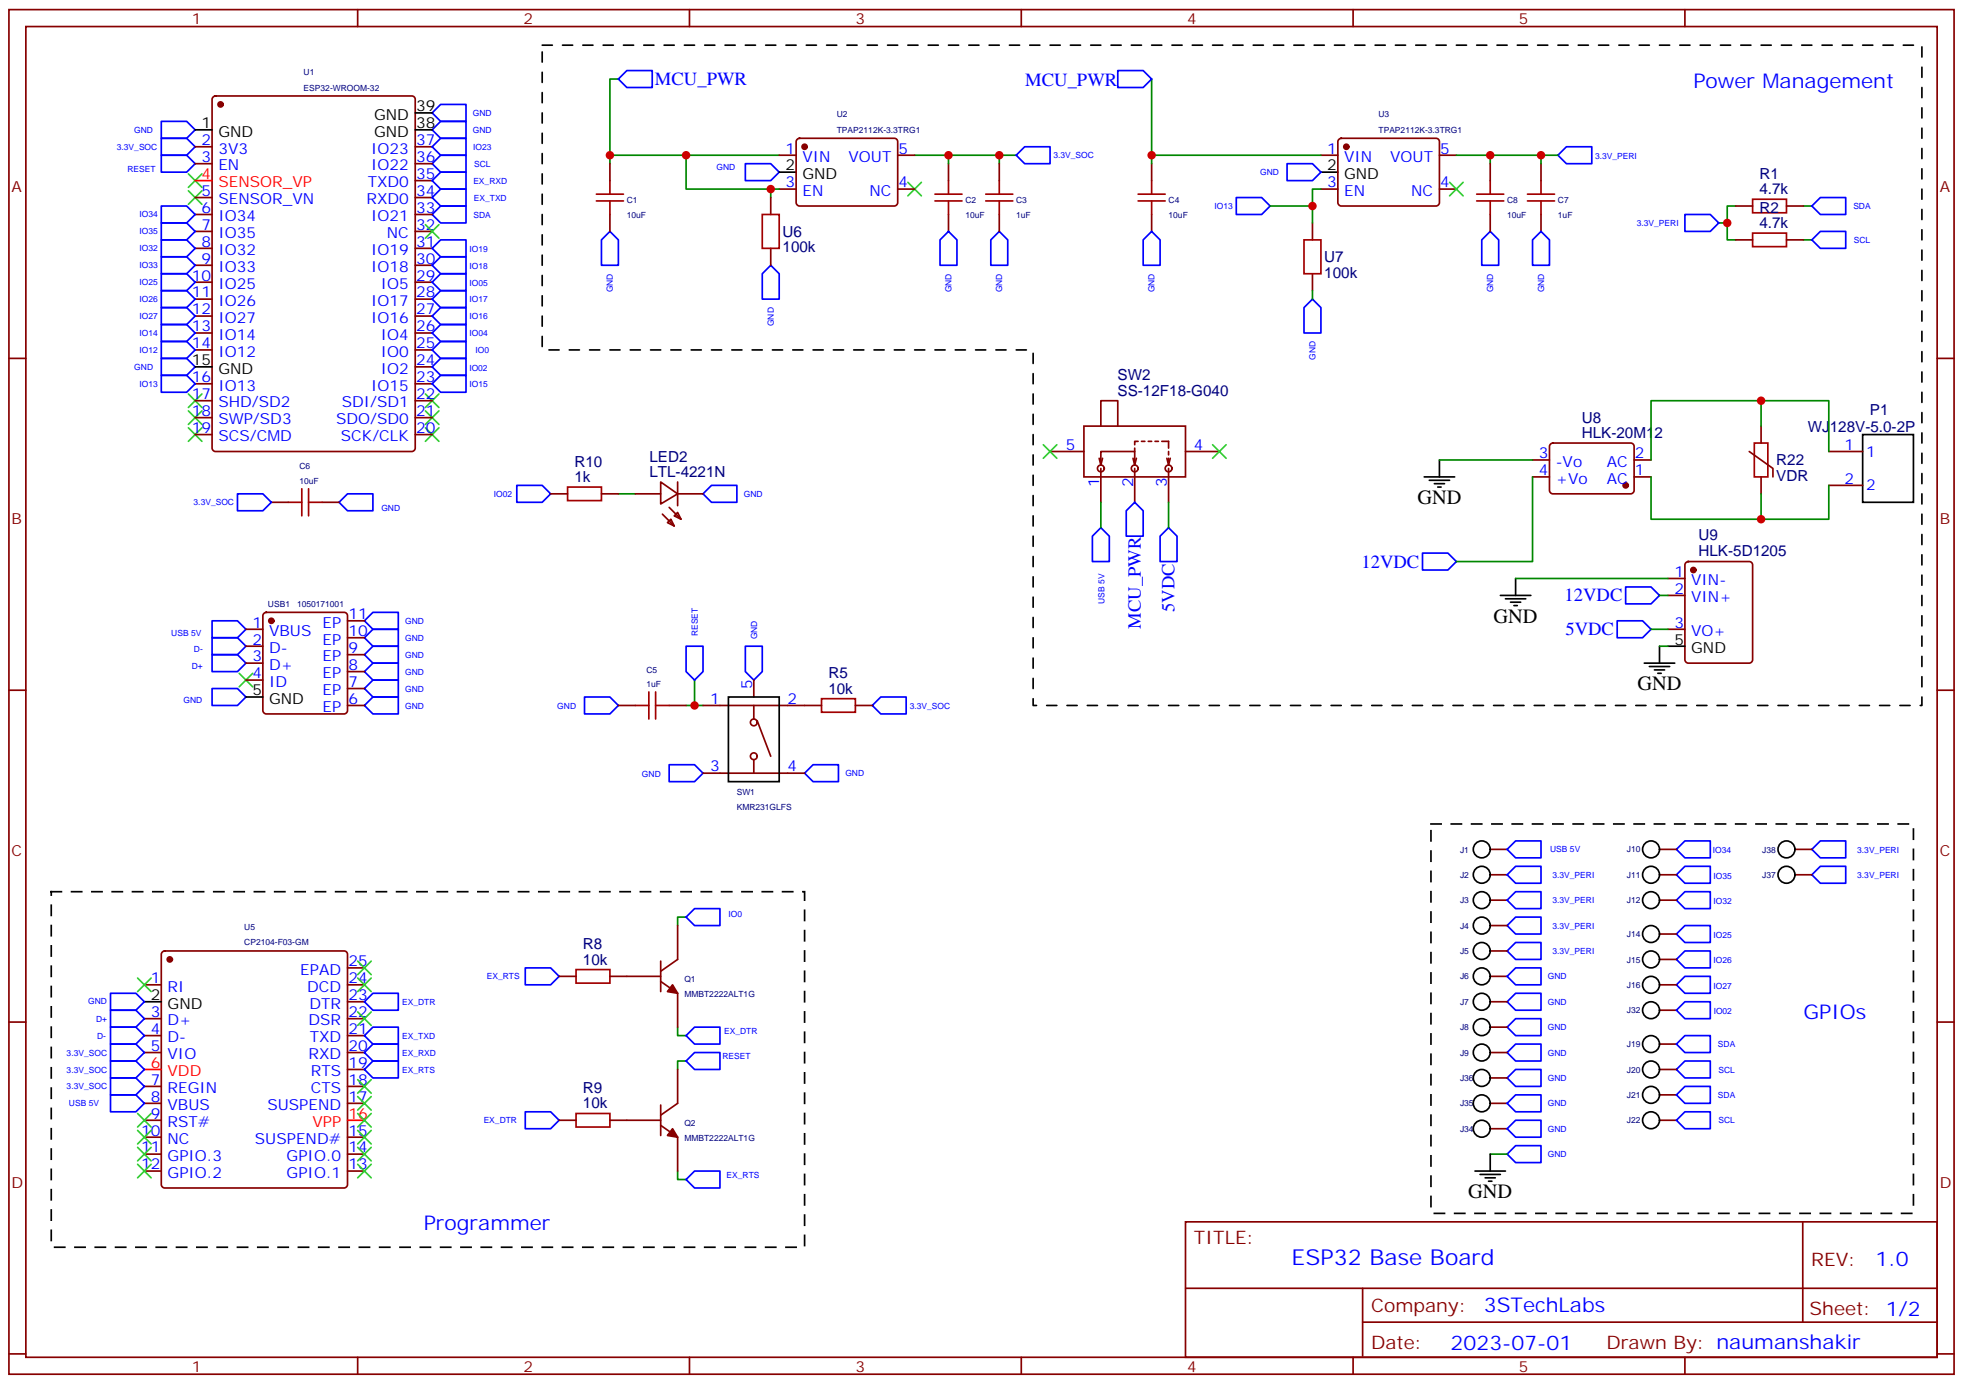
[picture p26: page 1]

A | A

1

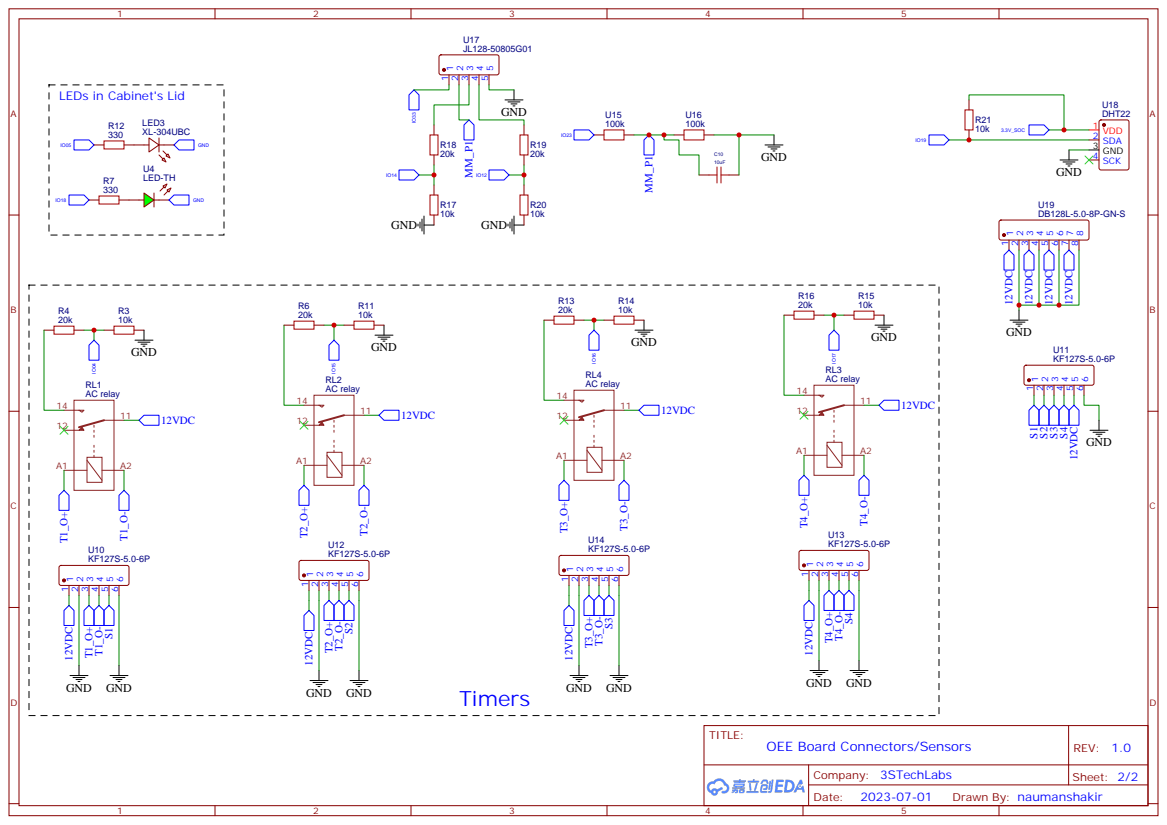
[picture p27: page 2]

LEDs in Cabinet's Lid

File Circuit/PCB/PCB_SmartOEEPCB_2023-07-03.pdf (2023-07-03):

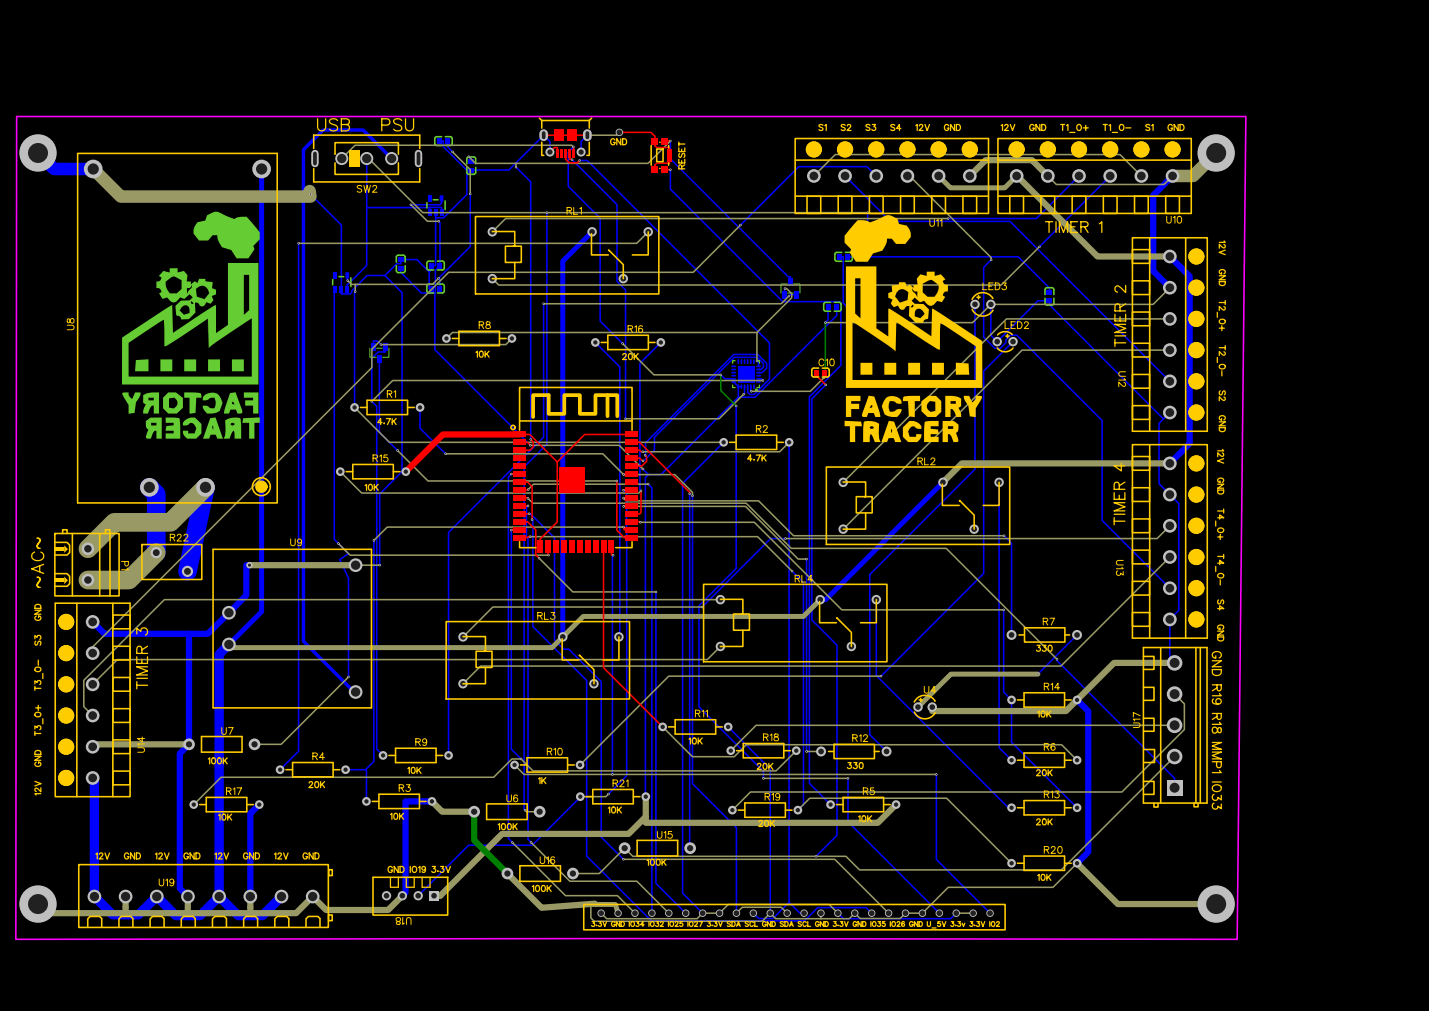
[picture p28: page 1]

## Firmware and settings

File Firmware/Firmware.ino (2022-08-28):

#include "dht22Handler.h"         //temperature and humidity functions
#include "photoSensor.h"          //IMU MPU6050 functions
#include "currentSesnorHandler.h" //current sensor functions
#include "headers.h"              //all misc. headers and functions
#include "esp32InternalTime.h"
#include "MQTTFuncs.h" //MQTT related functions
#include "webApp.h"    //Captive Portal webpages
#include <FS.h>        //ESP32 File System

const long interval = 1000 * 60 * 5;        // Interval at which to read sensors//5 mintues
Neotimer dataAcqTimer = Neotimer(interval); // Set timer's preset
Neotimer sensorsDataTimer = Neotimer(1000); // Set timer's preset

IPAddress ipV(192, 168, 4, 1);
String loadParams(AutoConnectAux &aux, PageArgument &args) // function to load saved settings
{
    (void)(args);
    File param = FlashFS.open(PARAM_FILE, "r");
    String v1 = "";
    String v2 = "";
    if (param)
    {
        Serial.println("load params func");
        aux.loadElement(param);
        Serial.println(param);
        // Serial.println(args);
        AutoConnectText &vibSValueElm = aux["vibSValue"].as<AutoConnectText>();
        AutoConnectText &curSValueElm = aux["curSValue"].as<AutoConnectText>();
        // vibSValueElm.value="VibS:91122";#
        Serial.println(vibSValueElm.value);
        v1 = String(vibSValueElm.value);
        v2 = String(curSValueElm.value);
        if (v1.length() > 0)
        {
            vibSValueElm.value = String("PhotoSensor: ") + getPhotoSensor();
        }
        if (v2.length() > 0)
        {
            curSValueElm.value = String("Current: ") + getCurrentWatts();
        }
        // curSValueElm.value="CurS:7788";
        param.close();
    }
    else
        Serial.println(PARAM_FILE " open failed");
    return String("");
}

String saveParams(AutoConnectAux &aux, PageArgument &args) // save the settings
{
    serverName = args.arg("mqttserver"); // broker
    serverName.trim();

    channelId = args.arg("channelid");
    channelId.trim();

    userKey = args.arg("userkey"); // user name
    userKey.trim();

    apiKey = args.arg("apikey"); // password
    apiKey.trim();

    timezone = args.arg("timezone"); // timezone
    timezone.trim();

    minActiveValue = args.arg("minActiveValue");
    minActiveValue.trim();

    ampSensorType = args.arg("ampSensorType");
    ampSensorType.trim();
    ampSensorType = ampSensorType.substring(0, 2);

    tempUnits = args.arg("tempUnits");
    tempUnits.trim();

    String upd = args.arg("period");
    upd = upd.substring(0, 2);
    sensorSelection = upd;

    apPass = args.arg("apPass"); // ap pass
    apPass.trim();

    settingsPass = args.arg("settingsPass"); // ap pass
    settingsPass.trim();

    hostName = args.arg("hostname");
    hostName.trim();

    // The entered value is owned by AutoConnectAux of /mqtt_setting.
    // To retrieve the elements of /mqtt_setting, it is necessary to get
    // the AutoConnectAux object of /mqtt_setting.
    File param = FlashFS.open(PARAM_FILE, "w");
    portal.aux("/mqtt_setting")->saveElement(param, {"mqttserver", "channelid", "userkey", "apikey", "timezone", "period", "minActiveValue", "ampSensorType", "tempUnits", "hostname", "apPass", "settingsPass"});
    param.close();

    // Echo back saved parameters to AutoConnectAux page.
    AutoConnectText &echo = aux["parameters"].as<AutoConnectText>();
    echo.value = "Server: " + serverName + "<br>";
    echo.value += "Channel ID: " + channelId + "<br>";
    echo.value += "Timezone: " + timezone + "<br>";
    echo.value += "Username: " + userKey + "<br>";
    echo.value += "Password: " + apiKey + "<br>";
    echo.value += "Sensor Settings: " + String(upd) + "<br>";
    echo.value += "Min Active Value: " + minActiveValue + "<br>";
    echo.value += "Amp Sensor Type: " + ampSensorType + "<br>";
    echo.value += "Temperature Units: " + tempUnits + "<br>";
    echo.value += "ESP host name: " + hostName + "<br>";
    echo.value += "AP Password: " + apPass + "<br>";
    echo.value += "Settings Page Password: " + settingsPass + "<br>";
    mqttPublish("OEEDevice/dev/config", String("tz;") + timezone); // publish timezone info
    return String("");
}
bool loadAux(const String auxName) // load defaults from data/*.json
{
    bool rc = false;
    Serial.println("load aux func");
    String fn = auxName + ".json";
    File fs = FlashFS.open(fn.c_str(), "r");
    if (fs)
    {
        rc = portal.load(fs);
        fs.close();
    }
    else
        Serial.println("Filesystem open failed: " + fn);
    return rc;
}
uint8_t inAP = 0;
bool whileCP()
{

    if (inAP == 0)
    {
        ledState(AP_MODE);
        inAP = 1;
    }
    // Serial.println("AP MODE");

    loopLEDHandler();
}

void setup() // main setup functions
{
    Serial.begin(115200);
    delay(1000);
    setupDHT22();
    setupPhotoSensor();
    setupCurrentSensor();

    if (!MDNS.begin("esp32")) // starting mdns so that user can access webpage using url `esp32.local`(will not work on all devices)
    {
        Serial.println("Error setting up MDNS responder!");
        while (1)
        {
            delay(1000);
        }
    }
#if defined(ARDUINO_ARCH_ESP8266)
    FlashFS.begin();
#elif defined(ARDUINO_ARCH_ESP32)
    FlashFS.begin(true);
#endif
    loadAux(AUX_MQTTSETTING);
    loadAux(AUX_MQTTSAVE);
    AutoConnectAux *setting = portal.aux(AUX_MQTTSETTING);
    if (setting) // get all the settings parameters from setting page on esp32 boot
    {
        Serial.println("Setting loaded");
        PageArgument args;
        AutoConnectAux &mqtt_setting = *setting;
        loadParams(mqtt_setting, args);
        AutoConnectInput &hostnameElm = mqtt_setting["hostname"].as<AutoConnectInput>();
        AutoConnectInput &apPassElm = mqtt_setting["apPass"].as<AutoConnectInput>();
        AutoConnectInput &serverNameElm = mqtt_setting["mqttserver"].as<AutoConnectInput>();
        AutoConnectInput &channelidElm = mqtt_setting["channelid"].as<AutoConnectInput>();
        AutoConnectInput &userkeyElm = mqtt_setting["userkey"].as<AutoConnectInput>();
        AutoConnectInput &apikeyElm = mqtt_setting["apikey"].as<AutoConnectInput>();
        AutoConnectInput &minActiveValueElm = mqtt_setting["minActiveValue"].as<AutoConnectInput>();
        AutoConnectRadio &ampSensorTypeElm = mqtt_setting["ampSensorType"].as<AutoConnectRadio>();
        AutoConnectRadio &tempUnitsElm = mqtt_setting["tempUnits"].as<AutoConnectRadio>();
        AutoConnectRadio &periodElm = mqtt_setting["period"].as<AutoConnectRadio>();
        AutoConnectText &vibSValueElm = mqtt_setting["vibSValue"].as<AutoConnectText>();
        AutoConnectText &curSValueElm = mqtt_setting["curSValue"].as<AutoConnectText>();
        AutoConnectInput &settingsPassElm = mqtt_setting["settingsPass"].as<AutoConnectInput>();
        // vibSValueElm.value="VibS:11";
        serverName = String(serverNameElm.value);
        channelId = String(channelidElm.value);
        userKey = String(userkeyElm.value);
        apiKey = String(apikeyElm.value);
        minActiveValue = String(minActiveValueElm.value);
        ampSensorType = String(ampSensorTypeElm.value());
        tempUnits = String(tempUnitsElm.value());
        sensorSelection = String(periodElm.value());
        hostName = String(hostnameElm.value);
        apPass = String(apPassElm.value);
        settingsPass = String(settingsPassElm.value);
        if (hostnameElm.value.length())
        {
            // hostName=hostName+ String("-") + String(GET_CHIPID(), HEX);
            //;
            // portal.config(hostName.c_str(), apPass.c_str());
            //  portal.config(hostName.c_str(), "123456789AP");
            config.apid = hostName; // hostnameElm.value+ "-" + String(GET_CHIPID(), HEX);
            config.password = apPass;
            config.psk = apPass;
            // portal.config(hostName.c_str(), "123456789AP");
            Serial.println("(from hostELM) hostname set to " + hostName);
        }
        else
        {

            // hostName = String("OEE");;
            // portal.config(hostName.c_str(), "123456789AP");
            config.apid = hostName; // hostnameElm.value+ "-" + String(GET_CHIPID(), HEX);
            config.password = apPass;
            config.psk = apPass;
            // config.hostName = hostName;//hostnameElm.value+ "-" + String(GET_CHIPID(), HEX);
            //  portal.config(hostName.c_str(), "123456789AP");
            Serial.println("hostname set to " + hostName);
        }
        config.homeUri = "/_ac";
        config.apip = ipV;

        portal.on(AUX_MQTTSETTING, loadParams);
        portal.on(AUX_MQTTSAVE, saveParams);
    }
    else
    {
        Serial.println("aux. load error");
    }
    // config.homeUri = "/_ac";
    config.apip = ipV;
    config.autoReconnect = true;
    config.reconnectInterval = 1;
    Serial.print("AP: ");
    Serial.println(hostName);
    Serial.print("Password: ");
    Serial.println(apPass);
    config.title = "OEE Sensing"; // set title of webapp

    // add different tabs on homepage
    portal.append("/api-now", "api-now");
    portal.append("/api", "api");
    portal.append("/LiveSensors", "LiveSensors");
    portal.append("/data", "DataTable");
    portal.disableMenu(AC_MENUITEM_DISCONNECT);
    server.on("/", handleRoot);
    server.on("/api-now", cmotsValues);
    server.on("/api", api);
    server.on("/LiveSensors", live);
    server.on("/data", dataTable);
    // Starts user web site included the AutoConnect portal.

    config.auth = AC_AUTH_DIGEST;
    config.authScope = AC_AUTHSCOPE_PARTIAL;
    config.username = hostName;
    config.password = settingsPass;

    portal.config(config);
    portal.whileCaptivePortal(whileCP);
    portal.onDetect(atDetect);
    portal.load(FPSTR(PAGE_AUTH));
    if (portal.begin())
    {
        Serial.println("Started, IP:" + WiFi.localIP().toString());
        ledState(AP_MODE);
    }
    else
    {
        Serial.println("Connection failed.");
        while (true)
        {
            yield();
            delay(100);
        }
    }

    MDNS.addService("http", "tcp", 80);
    mqttConnect(); // start mqtt
}

void loop()
{
    server.handleClient();
    portal.handleRequest();
    loopLEDHandler();
    if (dataAcqTimer.repeat())
    {
        // ss.calculateOEEValue();

        // OEEValue = ss.getOEEValue();
        ss.addSensorValue(getTimestamp(), getPhotoSensor(), getTemp(tempUnits), getHumid(), getCurrentWatts());
    }
    if (sensorsDataTimer.repeat())
    {
        ss.acquireAndStoreCurrentSensorValues_OEE(getCurrentWatts());
    }
    if (millis() - lastPub > updateInterval) // publish data to mqtt server
    {
        mqttPublish("OEE/" + String(hostName), getTimestamp() + String(";") + getTempHumid(tempUnits) + String(";") + getPhotoSensor() + String(";") + getCurrentWatts()); // publish data to mqtt broker
        ledState(ACTIVE_MODE);
        // uncomment the lines below for debugging
        //  Serial.println(ampSensorType);
        //  Serial.println(sensorSelection);
        //  Serial.println(minActiveValue);
        //  Serial.println(channelId);
        //  Serial.println(userKey);
        //  Serial.println(apiKey);
        //  Serial.println(apid);
        //  Serial.println(hostName);
        //  Serial.println(apPass);
        //  Serial.println(tempUnits)

        lastPub = millis();
    }
    if (!mqttClient.connected())
    {
        reconnect();
    }
    mqttClient.loop();
    if (WiFi.status() == WL_IDLE_STATUS)
    {
        ledState(IDLE_MODE);
        ESP.restart();

        delay(1000);
    }
}

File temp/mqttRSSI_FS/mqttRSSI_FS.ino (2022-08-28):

/*
  ESP8266/ESP32 publish the RSSI as the WiFi signal strength to ThingSpeak channel.
  This example is for explaining how to use the AutoConnect library.

  In order to execute this example, the ThingSpeak account is needed. Sing up
  for New User Account and create a New Channel via My Channels.
  For details, please refer to the project page.
  https://hieromon.github.io/AutoConnect/howtoembed.html#used-with-mqtt-as-a-client-application

  Also, this example uses AutoConnectAux menu customization which stored in SPIFFS.
  To evaluate this example, you upload the contents as mqtt_setting.json of
  the data folder with MkSPIFFS Tool ("ESP8266 Sketch Data Upload" in Tools menu
  in Arduino IDE).

  This example is based on the thinkspeak.com environment as of Dec. 20, 2018.
  Copyright (c) 2020 Hieromon Ikasamo.
  This software is released under the MIT License.
  https://opensource.org/licenses/MIT
*/

#if defined(ARDUINO_ARCH_ESP8266)
#include <ESP8266WiFi.h>
#include <ESP8266HTTPClient.h>
#define GET_CHIPID()  (ESP.getChipId())
#elif defined(ARDUINO_ARCH_ESP32)
#include <WiFi.h>
#include <WebServer.h>
#include <SPIFFS.h>
#include <HTTPClient.h>
#define GET_CHIPID()  ((uint16_t)(ESP.getEfuseMac()>>32))
#endif
#include <PubSubClient.h>
#include <AutoConnect.h>

/*
  AC_USE_SPIFFS indicates SPIFFS or LittleFS as available file systems that
  will become the AUTOCONNECT_USE_SPIFFS identifier and is exported as showng
  the valid file system. After including AutoConnect.h, the Sketch can determine
  whether to use FS.h or LittleFS.h by AUTOCONNECT_USE_SPIFFS definition.
*/
#include <FS.h>
#if defined(ARDUINO_ARCH_ESP8266)
#ifdef AUTOCONNECT_USE_SPIFFS
FS& FlashFS = SPIFFS;
#else
#include <LittleFS.h>
FS& FlashFS = LittleFS;
#endif
#elif defined(ARDUINO_ARCH_ESP32)
#include <SPIFFS.h>
fs::SPIFFSFS& FlashFS = SPIFFS;
#endif

#define PARAM_FILE      "/param.json"
#define AUX_MQTTSETTING "/mqtt_setting"
#define AUX_MQTTSAVE    "/mqtt_save"
#define AUX_MQTTCLEAR   "/mqtt_clear"

// Adjusting WebServer class with between ESP8266 and ESP32.
#if defined(ARDUINO_ARCH_ESP8266)
typedef ESP8266WebServer  WiFiWebServer;
#elif defined(ARDUINO_ARCH_ESP32)
typedef WebServer WiFiWebServer;
#endif

AutoConnect  portal;
AutoConnectConfig config;
WiFiClient   wifiClient;
PubSubClient mqttClient(wifiClient);
String  serverName;
String  channelId;
String  userKey;
String  apiKey;
String  apid;
String  hostName;
unsigned int  updateInterval = 0;
unsigned long lastPub = 0;

#define MQTT_USER_ID  "anyone"

bool mqttConnect() {
  static const char alphanum[] = "0123456789"
                                 "ABCDEFGHIJKLMNOPQRSTUVWXYZ"
                                 "abcdefghijklmnopqrstuvwxyz";  // For random generation of client ID.
  char    clientId[9];

  uint8_t retry = 3;
  while (!mqttClient.connected()) {
    if (serverName.length() <= 0)
      break;

    mqttClient.setServer(serverName.c_str(), 1883);
    Serial.println(String("Attempting MQTT broker:") + serverName);

    for (uint8_t i = 0; i < 8; i++) {
      clientId[i] = alphanum[random(62)];
    }
    clientId[8] = '\0';

    if (mqttClient.connect(clientId, MQTT_USER_ID, userKey.c_str())) {
      Serial.println("Established:" + String(clientId));
      return true;
    } else {
      Serial.println("Connection failed:" + String(mqttClient.state()));
      if (!--retry)
        break;
      delay(3000);
    }
  }
  return false;
}

void mqttPublish(String msg) {
  String path = String("channels/0011");
  mqttClient.publish(path.c_str(), msg.c_str());
}

int getStrength(uint8_t points) {
  uint8_t sc = points;
  long    rssi = 0;

  while (sc--) {
    rssi += WiFi.RSSI();
    delay(20);
  }
  return points ? static_cast<int>(rssi / points) : 0;
}

String loadParams(AutoConnectAux& aux, PageArgument& args) {
  (void)(args);
  File param = FlashFS.open(PARAM_FILE, "r");
  if (param) {
    aux.loadElement(param);
    param.close();
  }
  else
    Serial.println(PARAM_FILE " open failed");
  return String("");
}

String saveParams(AutoConnectAux& aux, PageArgument& args) {
  serverName = args.arg("mqttserver");
  serverName.trim();

  channelId = args.arg("channelid");
  channelId.trim();
  
  userKey = args.arg("userkey");
  userKey.trim();
  
  apiKey = args.arg("apikey");
  apiKey.trim();
  
  String upd = args.arg("period");
  updateInterval = upd.substring(0, 2).toInt() * 1000;

  String uniqueid = args.arg("uniqueid");

  hostName = args.arg("hostname");
  hostName.trim();
  
  // The entered value is owned by AutoConnectAux of /mqtt_setting.
  // To retrieve the elements of /mqtt_setting, it is necessary to get
  // the AutoConnectAux object of /mqtt_setting.
  File param = FlashFS.open(PARAM_FILE, "w");
  portal.aux("/mqtt_setting")->saveElement(param, { "mqttserver", "channelid", "userkey", "apikey", "period", "uniqueid", "hostname" });
  param.close();

  // Echo back saved parameters to AutoConnectAux page.
  AutoConnectText&  echo = aux["parameters"].as<AutoConnectText>();
  echo.value = "Server: " + serverName + "<br>";
  echo.value += "Channel ID: " + channelId + "<br>";
  echo.value += "User Key: " + userKey + "<br>";
  echo.value += "API Key: " + apiKey + "<br>";
  echo.value += "Update period: " + String(updateInterval / 1000) + " sec.<br>";
  echo.value += "Use APID unique: " + uniqueid + "<br>";
  echo.value += "ESP host name: " + hostName + "<br>";

  return String("");
}

void handleRoot() {
  String  content =
    "<html>"
    "<head>"
    "<meta name=\"viewport\" content=\"width=device-width, initial-scale=1\">"
    "</head>"
    "<body>"
    "<iframe width=\"450\" height=\"260\" style=\"transform:scale(0.79);-o-transform:scale(0.79);-webkit-transform:scale(0.79);-moz-transform:scale(0.79);-ms-transform:scale(0.79);transform-origin:0 0;-o-transform-origin:0 0;-webkit-transform-origin:0 0;-moz-transform-origin:0 0;-ms-transform-origin:0 0;border: 1px solid #cccccc;\" src=\"https://thingspeak.com/channels/{{CHANNEL}}/charts/1?bgcolor=%23ffffff&color=%23d62020&dynamic=true&type=line\"></iframe>"
    "<p style=\"padding-top:5px;text-align:center\">" AUTOCONNECT_LINK(COG_24) "</p>"
    "</body>"
    "</html>";

  content.replace("{{CHANNEL}}", channelId);
  WiFiWebServer&  webServer = portal.host();
  webServer.send(200, "text/html", content);
}
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

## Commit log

2022-08-28 added firmware, Readme
    [Circuit.fzz]
2022-10-15 updated current senosr
2023-07-03 added PCB files
    [BOM_SmartOEEBoard_2023-07-03.csv, PickAndPlace_SmartOEEPCB_2023-07-03.csv]
2024-01-14 BOM with links
    BOM with links
    [BOM_SmartOEEBoard_2023-07-03_with_links.csv]
